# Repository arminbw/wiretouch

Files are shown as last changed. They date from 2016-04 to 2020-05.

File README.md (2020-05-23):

# WireTouch

WireTouch is an open multi-touch tracker based on mutual (projected) capacitance sensing. It was designed and built to foster research in the field of human-computer interaction. Please visit http://www.arminbwagner.com/wiretouch for demos and background information. You may also want to have a look at this paper:

.

The authors are currently not working on further updates. Feel free to fork the project and extend it as you see fit.

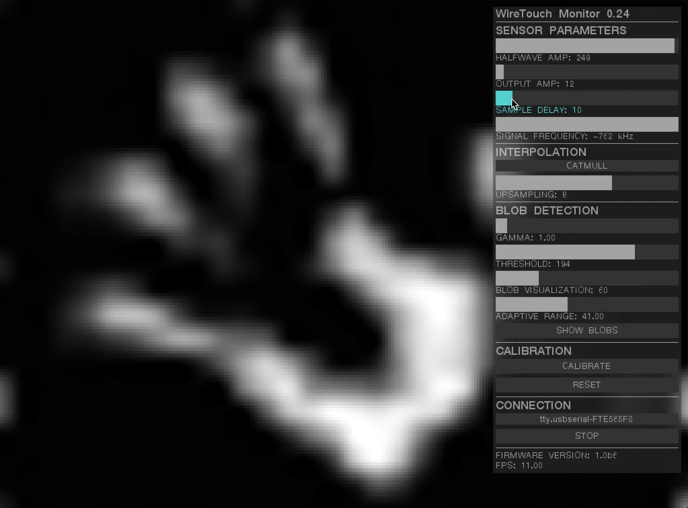
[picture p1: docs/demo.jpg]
WireTouch tracking software showing the interpolated measurements of a hand tracked human hand


## Building
### WireTouch Firmware
1. The heart of the WireTouch hardware is an ATmega328P microcontroller equipped with an Arduino bootloader. To upload the WireTouch firmware, connect the mainboard with your computer. Use an USB to serial UART FTDI 5V cable.

2. Open **hardware/v1.3/firmware/firmware.ino** in the [Arduino IDE](http://arduino.cc/en/Main/Software). Select **Tools>Board>Arduino UNO** and the correct port. **Upload the Arduino sketch.**

Please note: The patched FTDI driver is not working in the latest version of OS X. Please skip step 3 and just use the default (and unfortunately slower) standard Apple FTDI driver. 

~~3. Install the virtual com port [FTDI driver](http://www.ftdichip.com/Drivers/VCP.htm). You need to patch the FTDIUSBSerialDriver configuration to increase the symbol rate of the computer-mainboard connection (see [FTDI Application Note 120](http://www.ftdichip.com/Support/Documents/AppNotes/AN_120_Aliasing_VCP_Baud_Rates.pdf)). We prepared a little perl script for that. Run it as the superuser: ```sudo perl modify-ftdi-driver-settings.pl``` If you are running El Capitan (or a later Mac OS version) you will also have to deactivate the new system integrity protection (SIP) to make this work \(see [issue #1](https://github.com/arminbw/wiretouch/issues/1)\).~~

### WireTouch Monitor
1. Download [openFrameworks 0.8.4](https://github.com/openframeworks/openFrameworks).
2. Download the following openFrameworks addons and put them into your openFrameworks ```addons``` directory:.

  * [ofxCv](https://github.com/kylemcdonald/ofxCv)
  * [ofxUI](https://github.com/rezaali/ofxUI)
  * [ofxBlobsManager](https://github.com/peteruithoven/ofxBlobsManager)

3. Copy the wiretouch_monitor directory of this repository into your openFrameworks ```apps/myApps/``` directory.
4. We are currently using Xcode 7.3 on OSX 10.11.4 for development. Open the Xcode project. **Build it**.

Next to the openFrameworks addons we are also using several other 3rd-party libraries. You do not have to download them manually as they already reside inside the src/3rd-party directory (This list is just for future reference and to give credit).
* [cjson](https://github.com/DaveGamble/cJSON)
* [oscpack](http://code.google.com/p/oscpack)
* [TUIO C++ library](https://github.com/mkalten/TUIO11_CPP)

## License
WireTouch is free software: you can redistribute it and/or modify it under the terms of the GNU General Public License as published by the Free Software Foundation, either version 3 of the License, or (at your option) any later version.

A few of the included 3rd-party libraries are licensed under the GPL-compatible MIT license.

WireTouch is distributed in the hope that it will be useful, but WITHOUT ANY WARRANTY; without even the implied warranty of merchantability or fitness for a particular purpose. See the [GNU General Public License](http://www.gnu.org/licenses) for more details.

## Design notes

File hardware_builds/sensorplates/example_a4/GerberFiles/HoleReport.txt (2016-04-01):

Tool   Size   Count  Plated

 T1    0.0360    54     Yes

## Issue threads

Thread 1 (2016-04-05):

custom baud not supported by OSX El Capitan

arminbw, 2016-04-05:
The modified FTDI driver won't work in OSX 10.11 out of the box. The reason: every kernel extensions has to be signed now by a developer. And before, the developer has to request a [specific certificate from Apple](https://developer.apple.com/library/mac/documentation/Security/Conceptual/System_Integrity_Protection_Guide/KernelExtensions/KernelExtensions.html).

```sudo kextutil -l /System/Library/Extensions/FTDIUSBSerialDriver.kext```

will return

```Code Signing Failure: not code signed```

arminbw, 2016-04-06:
The current solution to this problem is to [deactivate the system integrity protection](https://developer.apple.com/library/mac/documentation/Security/Conceptual/System_Integrity_Protection_Guide/ConfiguringSystemIntegrityProtection/ConfiguringSystemInt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):
* Boot to Recovery OS by restarting your machine and holding down the Command and R keys at startup.
* Launch Terminal from the Utilities menu.
* Enter the following command:
```csrutil enable```

Closed 2016-04-13.

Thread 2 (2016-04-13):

Mesuare capacitance

Mewiss, 2016-04-13:
Hi! I'm making a simple touch screen and I'm having problems with connections to measure capacitance. Do you have any full schematic or diagram about this part.

Thanks!

arminbw, 2016-04-13:
Hi! Which connections exactly are troubling you?

Mewiss, 2016-04-14:
I dont' understand how you connect electrodes with sensor board

arminbw, 2016-04-15:
We connected our sensor panel directly to the sensor board using 2.54mm pin headers. Of course you can use whatever connection you want. Just keep in mind that long cables might diminish the signal quality.

Closed 2016-04-22.

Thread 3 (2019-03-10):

Can't get image from the WireTouch Monitor

hongyu4671, 2019-03-10:
Hi guys,

I have followed the Wiretouch project description step by step. When the circuit (v1_30) and the sensor plate are finished, I have changed all parameters, unfortunately still can not get any image. When I change the “HALFWAVE AMP” in WireTouch Monitor 0.24, nothing changed (see in attachment "Screen Recording").  The parameters look like worked well.

> OSX Version: 10.14.3
> Xcode Version: 9.2
> (I used OPA2350EA/250 for main-board, sensor-board and signal-board).

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

Does anyone have the same problem?
#Question

Closed 2019-03-10.

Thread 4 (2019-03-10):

Can't get image from the Wiretouch Monitor

hongyu4671, 2019-03-10:
Hi guys,

I have followed the Wiretouch project description step by step. When the circuit (v1_30) and the sensor plate are finished, I have changed all parameters, unfortunately still can not get any image. When I change the “HALFWAVE AMP” in WireTouch Monitor 0.24, nothing changed (see in attachment "Screen Recording").  The parameters look like worked well.

> OSX Version: 10.14.3
> Xcode Version: 9.2
> (I used OPA2350EA/250 for main-board, sensor-board and signal-board).

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

Does anyone have the same problem?
#Question

arminbw, 2019-03-14:
Hi Hong,

Your build looks great! Let’s hope we can get it to going soon.

I’ve had a look at the video you sent me and the images look a bit too uniform to me. Also, the halfwave amp doesn't seem to do much at all. But before we go into that, please try the following:
- Set *sample delay* to 1.
- Set *output amp* to 1.
- Set the *frequency* to something high, like 640 kHz or higher.
- Now turn up the *halfwave amp* until the first white dots start to appear on the black screen.
- Now hold your hand above the sensor matrix. Put something in-between the wires and your hand. Don’t touch the wires themselves. Now slowly turn up the output amp until you see your hand.

If you still get nothing, you will need an oscilloscope to narrow down the problem.
- First of all alter the firmware, so it only measures a single crosspoint. I am doing that in my video at <a href="https://www.youtube.com/watch?v=rSD9vQ2_fLQ&feature=youtu.be&t=417">7:18</a>. Set `sample = measure_one(4, 4);` Now you are measuring a single point in the upper left corner of the matrix.
* Now search for the signal where the signal board connects with the sensor matrix. One of the "columns" of the matrix should show a clean 5V wave. If not, something is wrong on the signal board – or the main board.
* If you found your wave, let’s check the sensor board. Be careful, though. You don’t want to short circuit anything! First open the sensor-board_v1_3.brd file to get an overview. Then have a look at PIN 5 of U13 (the first multiplexer). Does the oscilloscope show a wave? Does its amplitude decrease when you put your fist over the upper left corner of your matrix?

hongyu4671, 2019-03-20:
Dear Armin,

thanks for your reply.

After I set the sample delay to 1, output amp to 1 and frequency to 640kHz, I try to increase the halfwave amp to get some dots. Only when I set gamma to 16.00, then I can get some grey dots. But I can't get the hand shape by turning the output amp(video in attachment).

As you said, I set sample = measure_one(4, 4), at first, I can get a 5v wave from pin7 in signal board (picture in attachment). I felt there have some open circuit in the signal board (I use a socket to connect the ICs), after I presse the Multiplexer in signal board then I can't get any thing.

I will make new main and signal board. If I get something new, I will update this issue.

Thanks a lot for your advices!

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

arminbw, 2019-03-30:
I am not sure, if I understood you correctly. When you *remove* the multiplexer from your signal board, you can measure a 5V wave at P7 (compare attachment)?

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

hongyu4671, 2019-04-07:
Dear Arminbw,

I have made new main, signal and sensor board (without socket). As you suggested, I have measured some pins.

- with code: measure_one(4, 4)
I got a 5v from pin5 of Signal_board
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

- with code: measure_one(4, 4)
I got a wave from PIN5 of U13 of Sensor_board. After I **_press_** the matrix, the Vmin and Vbas decreased, Vpp increased. (Without press, just touch the matrix, the signal can not decrease that much)
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

- with code: measure_one(m, l)
the pins, which connect with the matrix, seemed like work well. (The signals have the shift)
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

- with code: measure_one(m, l)
when I pressed the matrix, I can only see some black lines. I can not tune the parameters to get the hand shape.
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

Thanks a lot for your advices!

arminbw, 2019-04-13:
OK, let me try to sum this up: You rebuild all boards and you get different results now. So there was something wrong with the old ones. I suspect there was a short on the signal board, but we don't know for sure.

The measurement you made with measure_one(4,4) on the new setup tells us the following:

* The signal board is sending a nice 5V square wave to the sensor matrix.

* The sensor board is receiving the coupled wave.

* The observable changes on PIN5 on UI13 are very small.

Please note: the matrix shouldn't be pressed. We are not measuring contact or pressure, but proximity by altering the electrical field.

I covered my sensor matrix with a 1.5mm thick glass plate, which I took out of a picture frame. Please try that or something similar and see if you can still see small changes on PIN5 of U13 on the sensor board when you put your fist on the upper left corner of the matrix (measure_one(4,4)). The difference can be very subtle, but it should be still noticeable on the oscilloscope. The image I attached shows what I get at 132kHz and at ca. 750kHz.

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

If your measurements look different, you might want to try other surface materials. Also try using different wires for your sensor matrix. Don't rebuild the whole matrix. Just build a single cross point for testing purposes.

If you get something similar, you should be able to measure the same signals where the sensor board connects with the mother board - on P4. Now follow the traces further. Measure PIN3 of OPAMP-3 on the motherboard while pulling up the "halfwave amp" in the GUI. How does it look like? Can you still spot a difference when you put your fist on the glass?

arminbw, 2019-04-13:
As a side note: I think it’s a typo, but if you want to measure the whole matrix, change the firmware code back to `measure_one(k, l)` not `measure_one(m, l)`.

hongyu4671, 2019-04-22:
I have changed the cover material to 1.5mm glass. As you suggested, I use two Dupont Line to make the cross. Now I can get some big change of the signal.

- Code: measure_one(4,4)    I can get nearly 1V change from the Pin5 of U13
Before put fist (Pin5 of U13)
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
After put fist (Pin5 of U13)
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

- Code: measure_one(4,4)    when I change "halfwave amp" signal from Pin3 of OPAMP-3 (mother board) can get the change as in the following pics
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

- Code: measure_one(4,4)    When I put my fist on the glass, I can see some change in the viewer of GUI. When I put my fist on, It seems like more dots came out
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

The PCB boards seems like works good, is it time to rebuild the matrix on glass?

Btw, its a typo for the (m, l)

arminbw, 2019-04-25:
Image 1 and 2 look pretty good.

Regarding image 3 and 4, where you measure Pin3 of OPAMP-3: Did you reduce the frequency (269kHz?) here to get better measurements? If not, something might be wrong here. And can you still see a difference in the wave when you lift and lower your fist?

Please don’t rebuild the matrix until we get a clear visual difference on the screen. I am not speaking of some dots. The whole screen should turn from black to white while you lower your fist on the crosspoint.

arminbw, 2019-05-26:
Hi Hong, did you make any progress? Can I support you in any way?

hongyu4671, 2019-05-28:
Dear Armin,

these days I have to solve other project problem, next month I will check the circuit.

And one more question, I want to use the circuit and the software for a thin films structure (bottom and top electrode: 50nm gold, insolation layer: 100nm Al2O3). Is it possible to use the circuit and software for the thin film device?

Best regards,
Yu Hong
在 2019年5月26日 +0200 17:04，Armin <notifications@github.com>，写道：
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

hongyu4671, 2019-06-19:
Hi Arminbw,
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
hongyu4671, 2019-06-19:
And one more thing, I turn off oscilloscope, remove the connection from Pin3 of OPAMP-3, but still connect the ground pin from mainboard with the oscilloscope's ground, the result are good as below.
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

hongyu4671, 2019-06-20:
Hi Arminbw,

If I didn't misunderstand the code, _**measure_one(k, l)**_,  when we change the **_k_**, the signal from signal board should change.

When we use _**measure_one(0, 0)**_, the signal should come from Pin 1 of signal board,
_**measure_one(1, 0)**_, signal should from Pin 2, right?

But when I change the code, the signal doesn't have any change, It comes always from **Pin 7** and **Pin 23**, which should get with code _**measure_one(6, l)**_ and _**measure_one(22,l)**_

All the signals are same like bellow.
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

arminbw, 2019-07-08:
Hi Hong,

a change from 25mV to 18mV seems pretty good to me. The video you posted (where you are using 640kHz) looks good too, but the screen should be black when your hand is raised, not grey.

Try to reduce the halfwave amp a bit while lifting your hand. Turn it lower than 247. The screen should be black. Then try to increase the output amp a little bit (higher than 1). When the screen turns grey, reduce the output amp a bit again, so the screen is black again. It can be a bit tricky to get the best range/sensitivity.

Regarding your other question: Yes, grounding the oscilloscope while making measurement helps. The motherboard has an extra pin to support that. Just be careful to not short anything. And yes, grounding the board and making measurements can alter the images you will see. Grounding your laptop (connecting it with a different power supply etc.) might also change the results. Unfortunately there are lots of variables.

Regarding your last post: **Yes, `measure_one(0,0)` should only send the signal to Pin 1.** If you see the wave at Pin 7 and/or Pin 23, something is wrong. Maybe the software isn't running – or maybe the multiplexer isn't working correctly. You could test this with the oscilloscope.
**The following image shows what mux1 should do when you set `sample = measure_one(1, 0).`**

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

hongyu4671, 2019-07-15:
Hi arminbw,

I have tested the 2 MUX in signal board, the signal looks good. I think last time, I forgot to run the software.

- With code **measure_one(1,1)**, after tuning the parameter I can get the screen from black to grey (when my fist touch the wire), when my other hand hold the ground, it can go to white (when my fist touch the wire).
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
with the circuit below:
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

- With code  **measure_one(1,1)**, when I changed the circuit to 6 signal lines, 8 sensor lines (circuit below), I can not get the same good result as before.
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

- With code **measure_one(k, l)**, (k=6, l=8), noise came up, and it can not be removed.
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

arminbw, 2019-10-17:
Hi Hong, sorry for the long delay. I will try to replicate your setup over the weekend.

arminbw, 2019-11-24:
I am trying to sum up your last post and comment on it point-by-point:

* Your MUX seems to work correctly. That’s good!
* `measure_one(1,1)` gives you promising results. Looking at your photo, I would suggest putting the glass **not in-between** the wires, but **on top of it**. Your hand should not touch the wires directly.
* When you set `signalboardWires = 6` and `sensorboardWires = 8` you get diagonal black lines. The lines you are seeing are not necessarily noise. Your board´s firmware is sending 6x8 crosspoints to your computer, but wiretouch.app is still expecting 32x22 crosspoints. To get a correct visualization you would need to change the values in `wtmApp.h` and then re-compile the software.

An easier way to quickly check if your small 6x8 build is working, is to set your firmware code back to 32x22 crosspoints. The screen should turn all white with a little black rectangle inside.

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

I tried to replicate your setup (see pictures above). I can track some movement in the black area, but there is a lot of noise bleeding in. I would suggest to increase the distance of the wires (e.g. 1cm x 1cm squares) and to try different wire gauges. I’m sorry that I can’t give you better advise at the moment than to basically ”play with all parameters”. Debugging hardware prototypes remotely is …not easy.

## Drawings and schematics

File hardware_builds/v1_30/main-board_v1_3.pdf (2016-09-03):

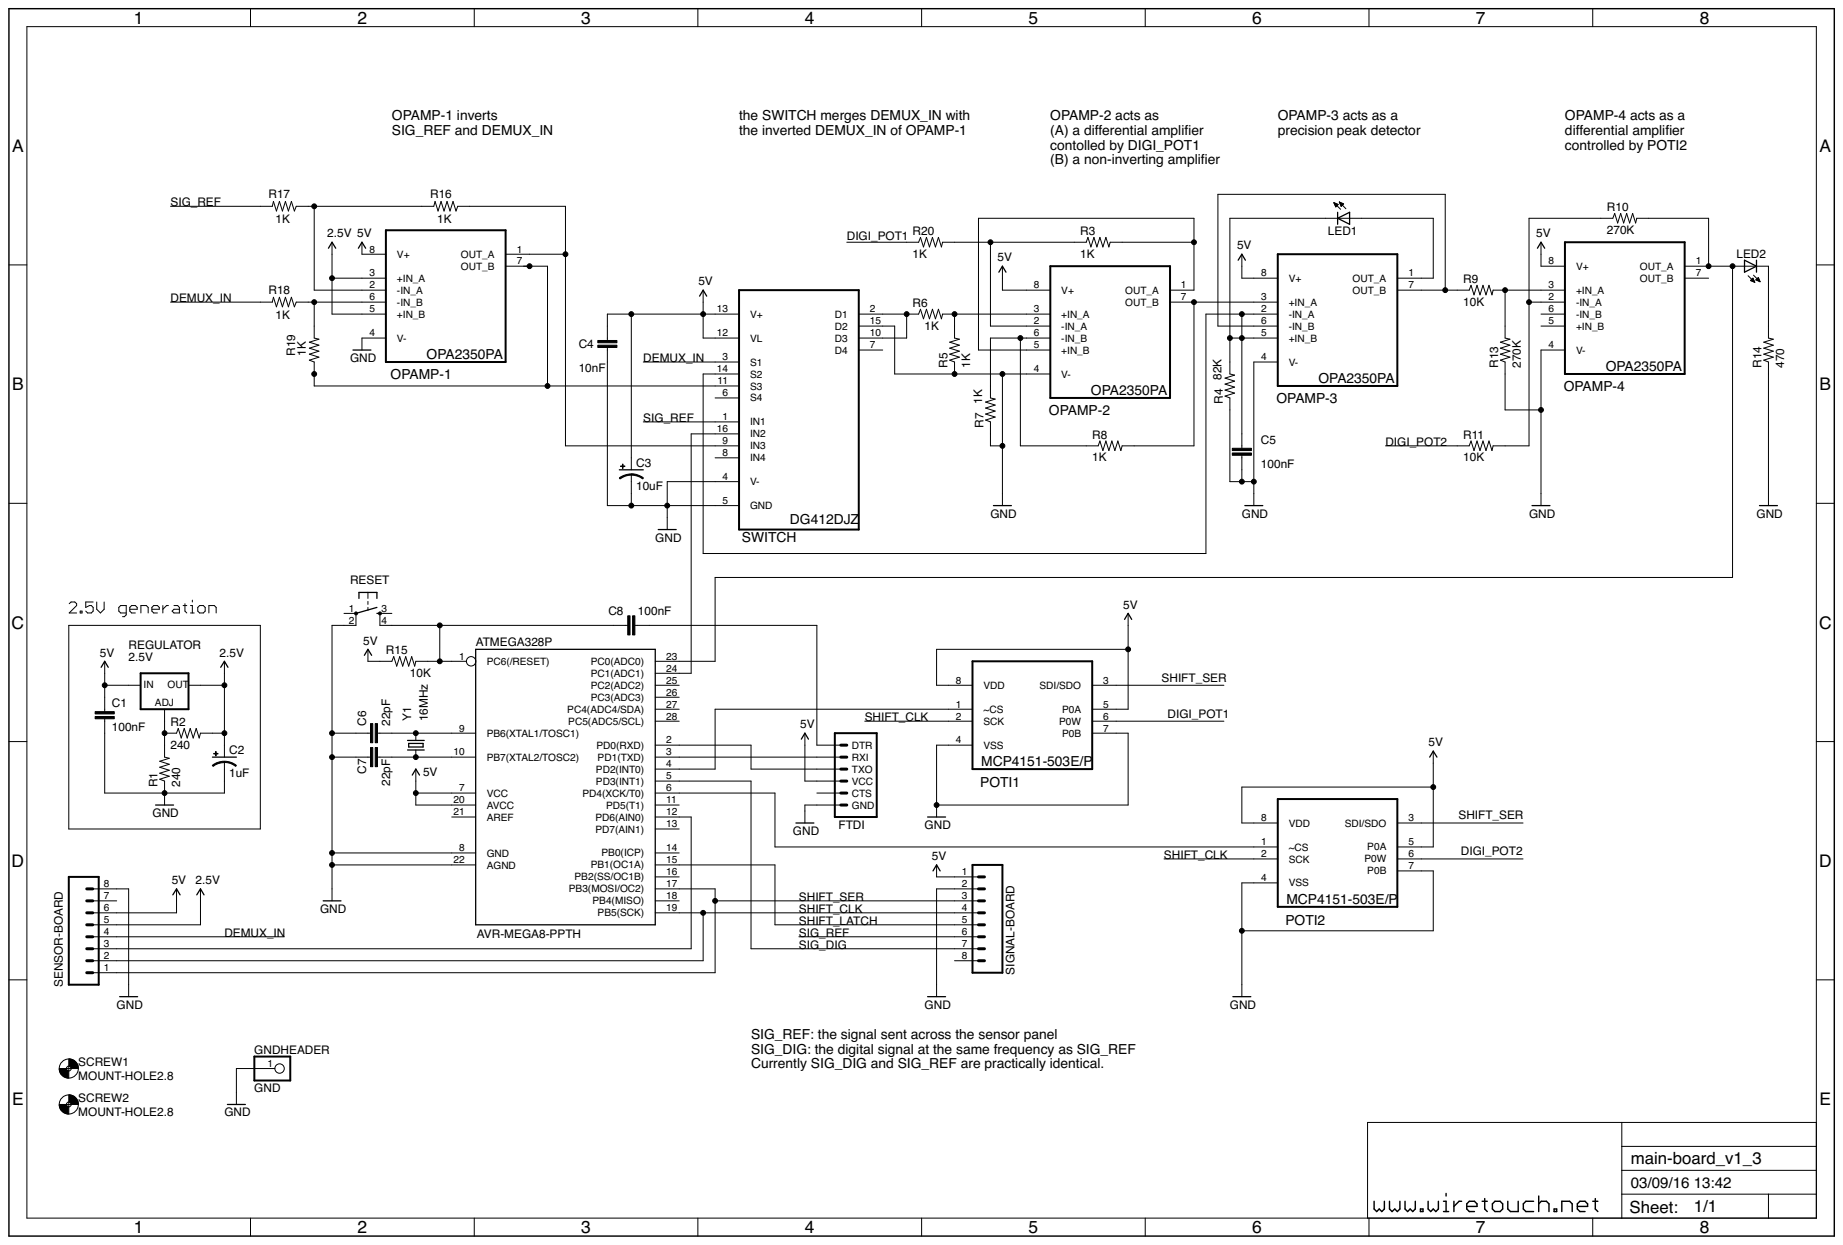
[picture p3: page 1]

(B) a non-inverting amplifier OPAMP-1 inverts SIG_REF and DEMUX_IN

the SWITCH merges DEMUX_IN with
the inverted DEMUX_IN of OPAMP-1

differential amplifier controlled by POTI2 OPAMP-2 acts as
(A) a differential amplifier contolled by DIGI_POT1

SIG_REF: the signal sent across the sensor panel SIG_DIG: the digital signal at the same frequency as SIG_REF Currently SIG_DIG and SIG_REF are practically identical.

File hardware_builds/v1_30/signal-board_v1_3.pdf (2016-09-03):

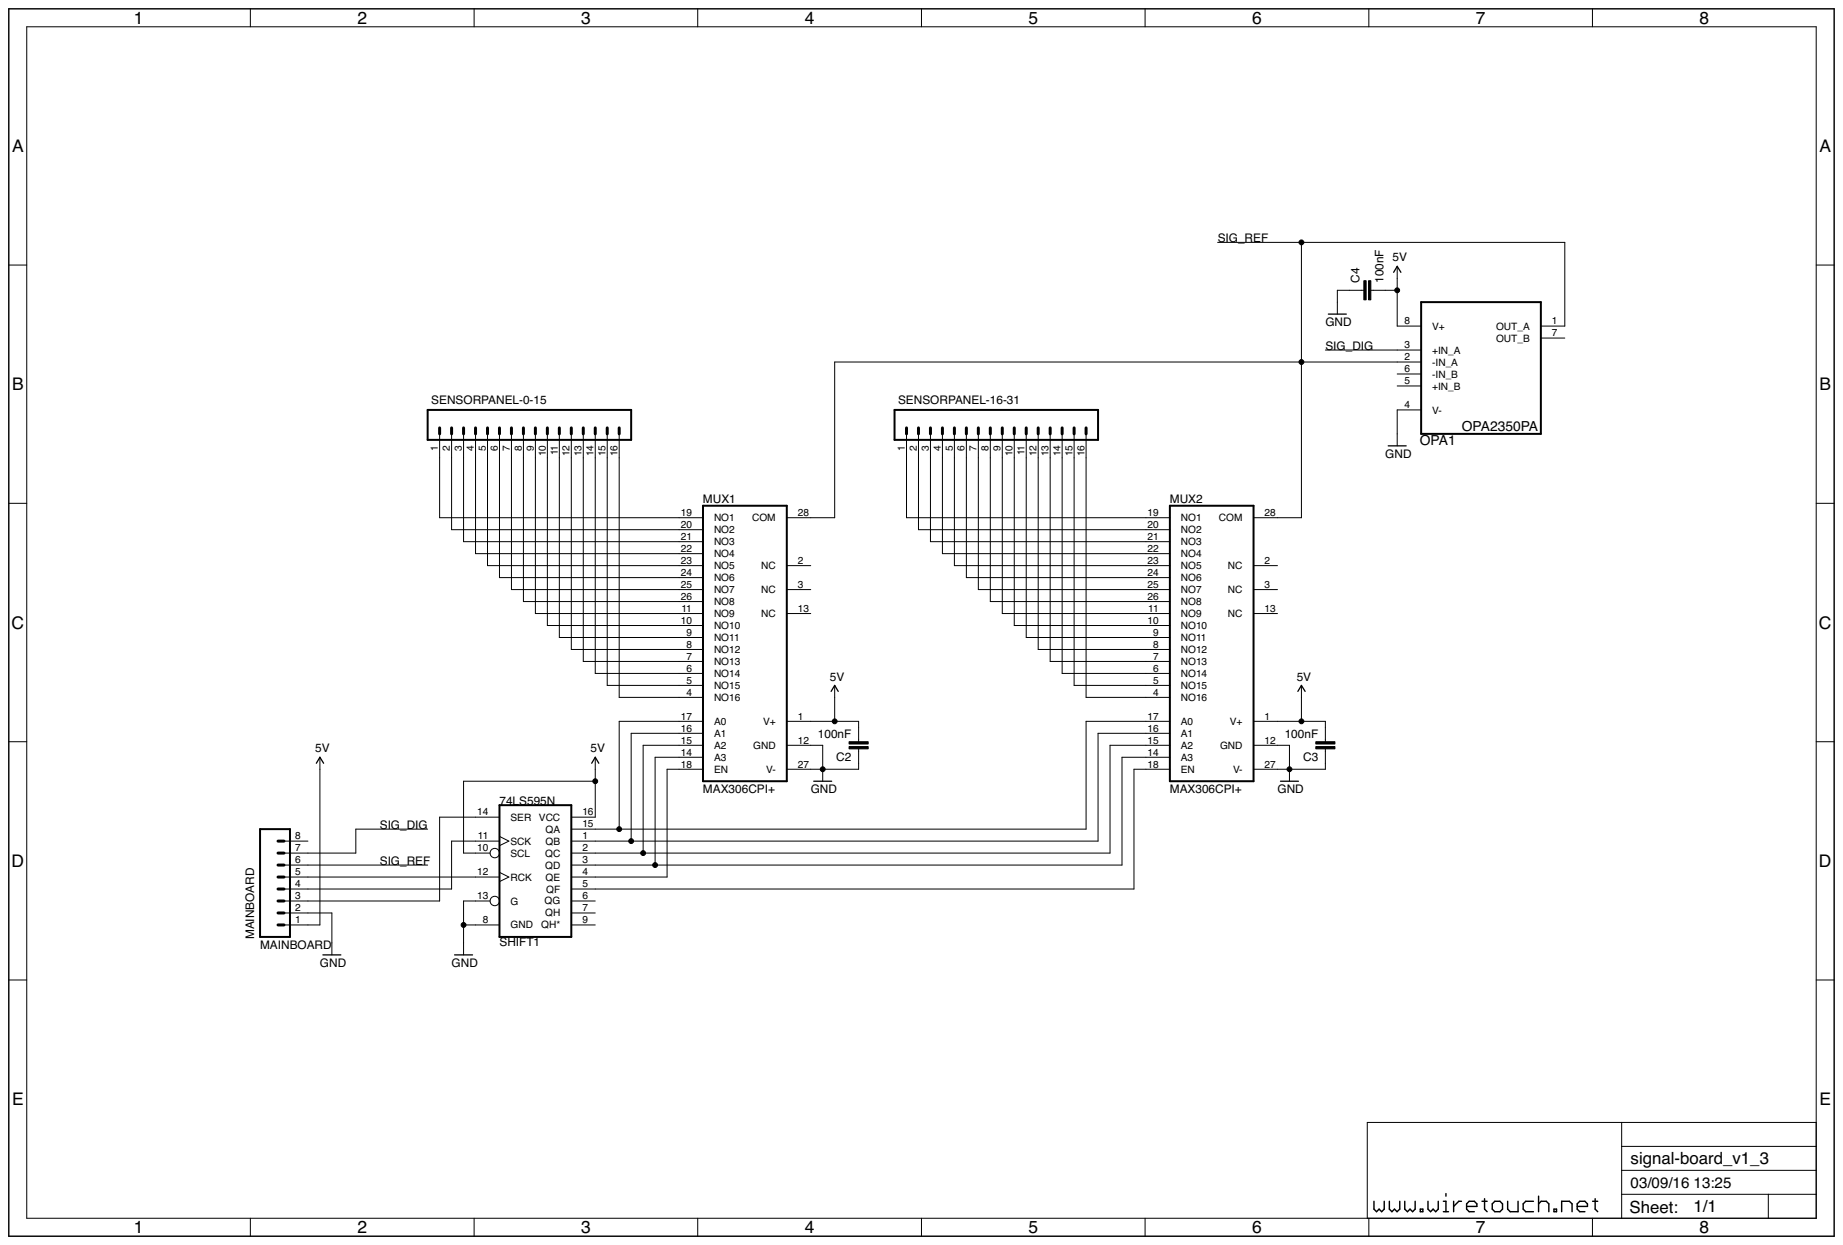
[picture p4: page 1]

4 | | | 13 | | 4 QF
3 | | | | | 5 QG
2 | | 8 | | 6 QH

1 | GND

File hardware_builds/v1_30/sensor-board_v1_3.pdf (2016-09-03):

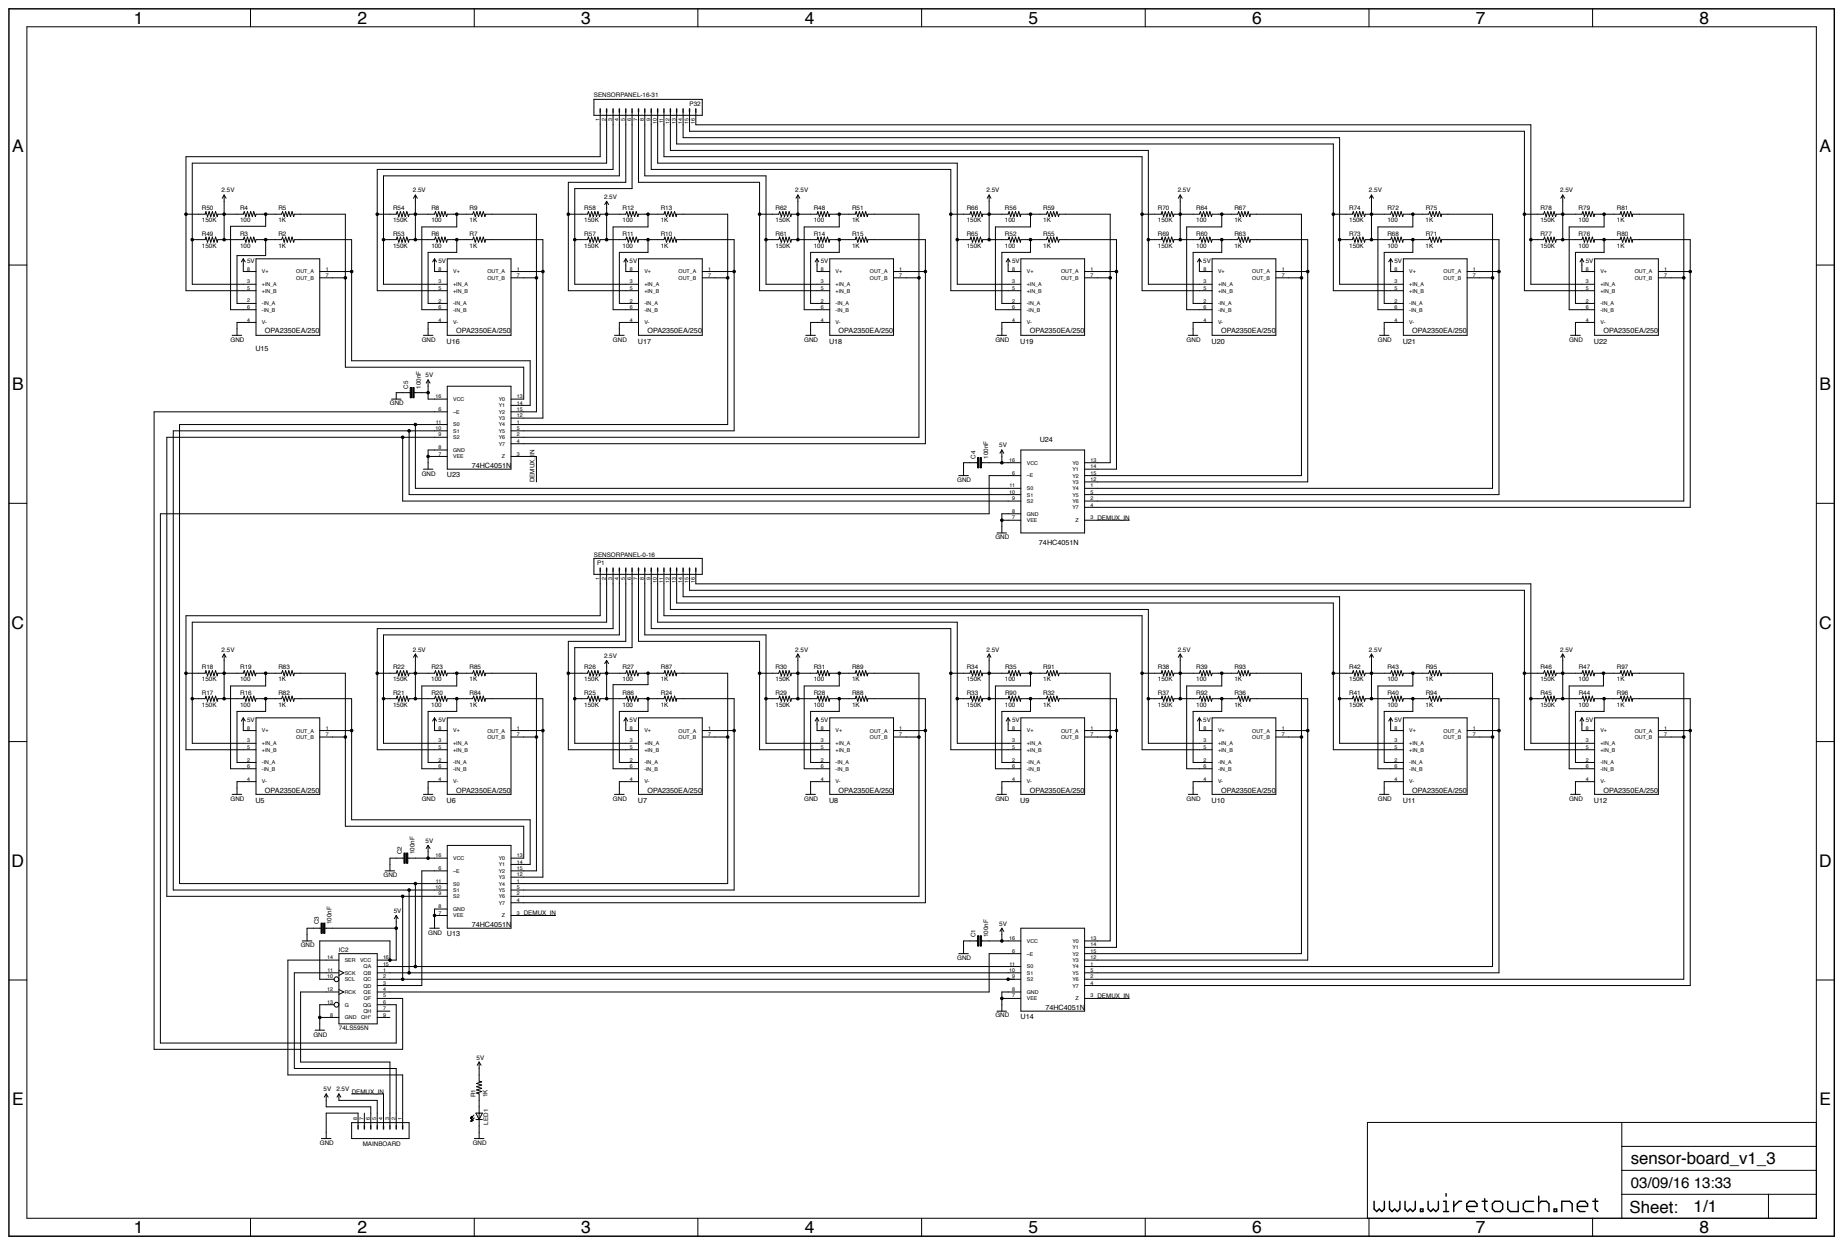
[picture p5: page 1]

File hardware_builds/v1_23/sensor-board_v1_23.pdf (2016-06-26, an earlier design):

A

A

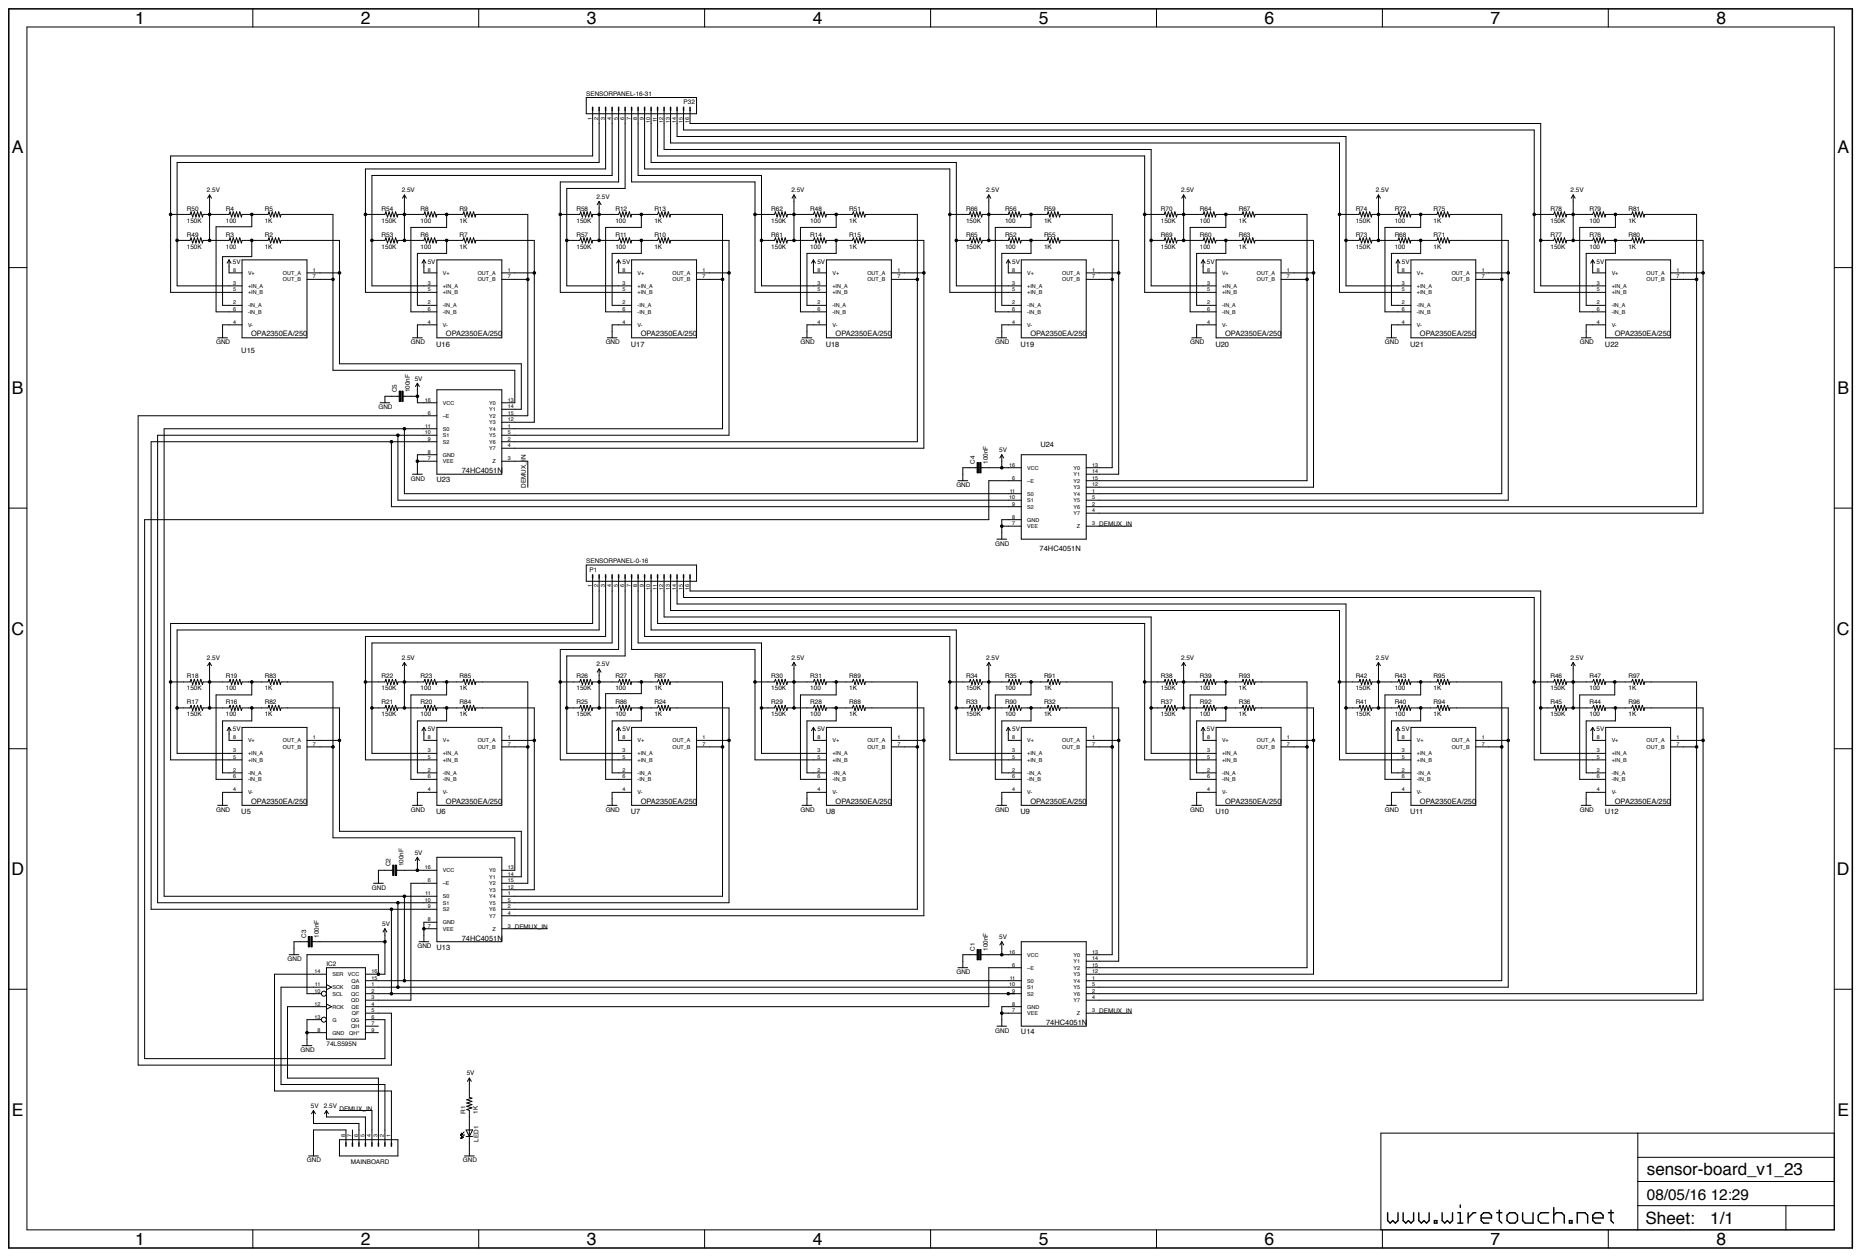
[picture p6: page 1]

S1 10
S2 9
GND 8 VEE 7

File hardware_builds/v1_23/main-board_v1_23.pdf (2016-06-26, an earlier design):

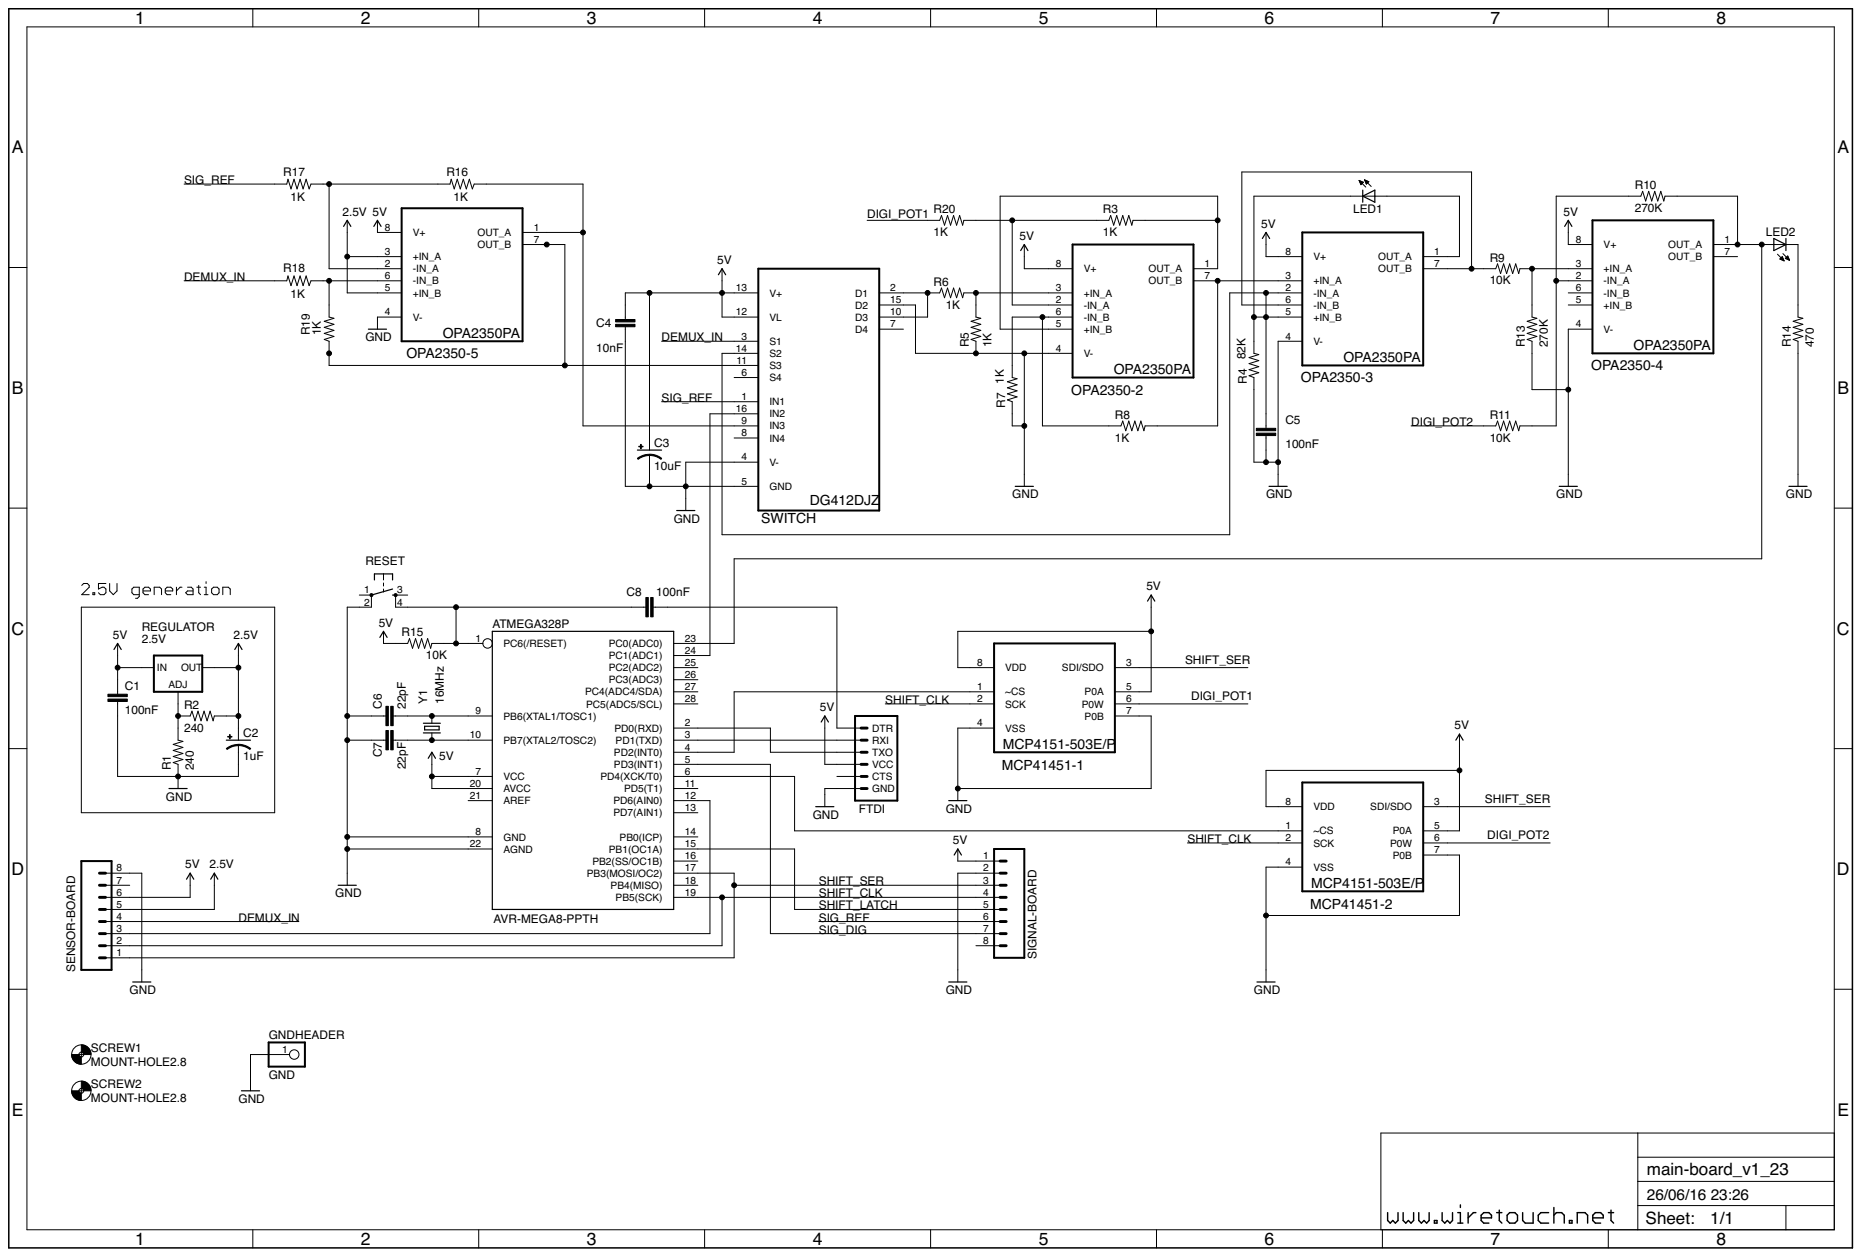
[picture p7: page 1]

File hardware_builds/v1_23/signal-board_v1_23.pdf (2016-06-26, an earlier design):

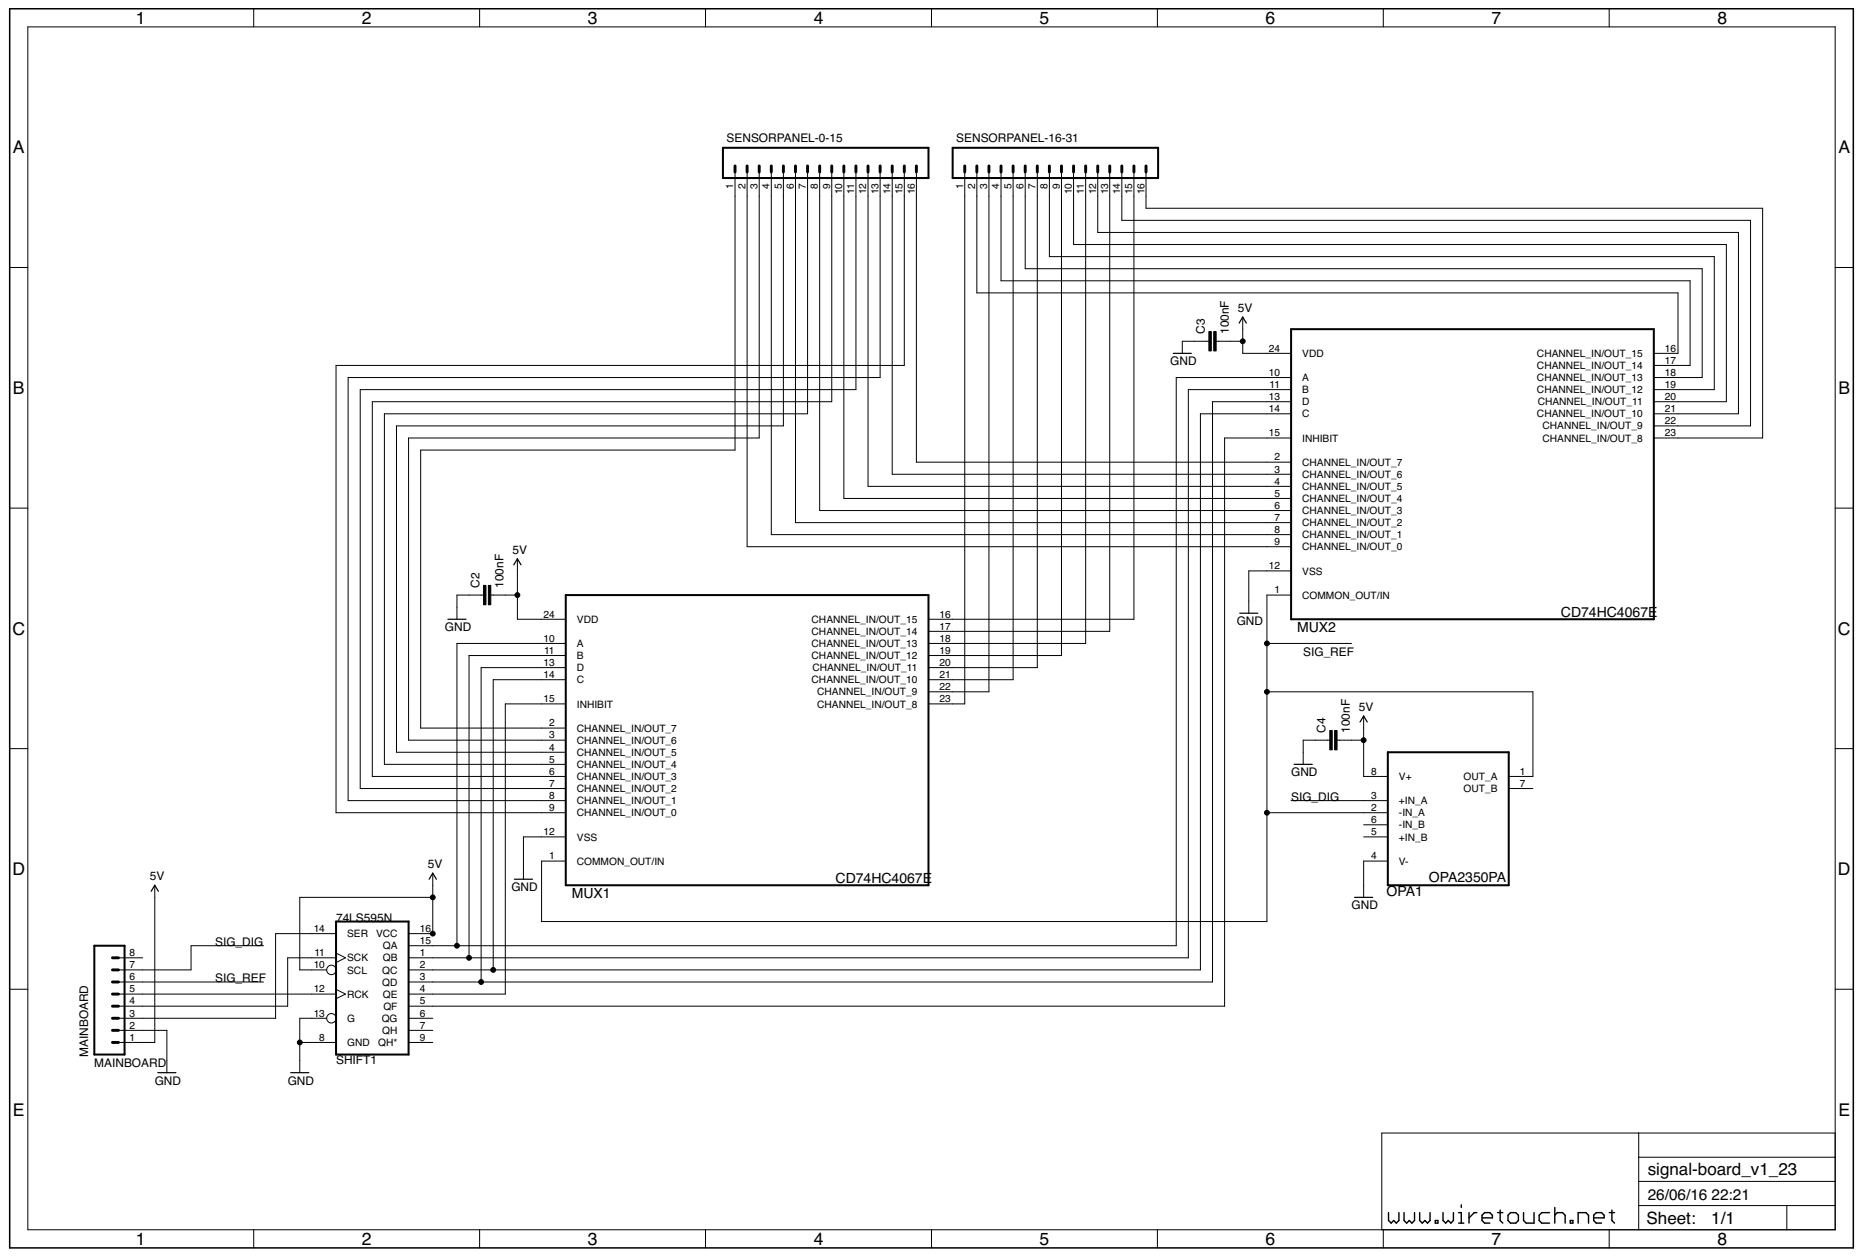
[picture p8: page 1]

17 CHANNEL_IN/OUT_13 18 CHANNEL_IN/OUT_12

19 CHANNEL_IN/OUT_11
20 CHANNEL_IN/OUT_10
21 CHANNEL_IN/OUT_9

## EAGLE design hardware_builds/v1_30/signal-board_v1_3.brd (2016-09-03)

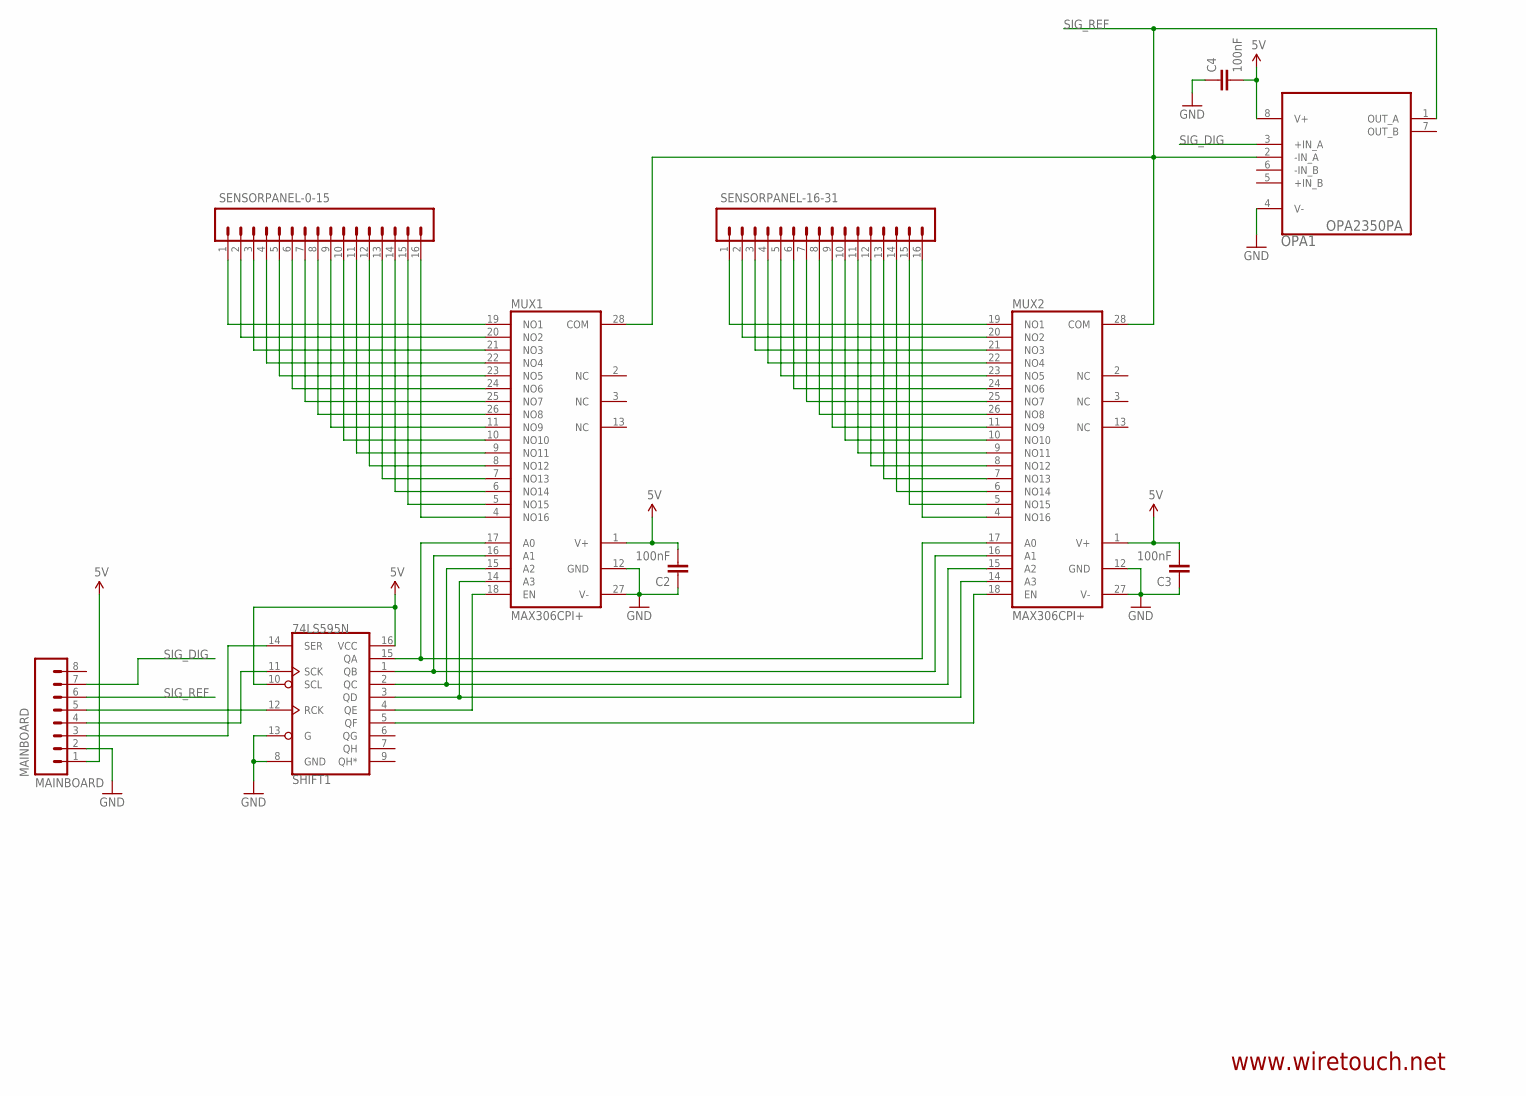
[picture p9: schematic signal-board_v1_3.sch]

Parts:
C2, C3, C4: 100nF; CAP-PTH-SMALL
MAINBOARD: MAINBOARD; 1X08_LONGPADS
MUX1, MUX2: MAX306CPI+; DIL28-6
OPA1: OPA2350PA; DIP254P762X508-8
SENSORPANEL-0-15, SENSORPANEL-16-31: M16LOCK_LONGPADS; 1X16_LOCK_LONGPADS
SHIFT1: 74LS595N; DIL16

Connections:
5V: C2.2, C3.2, C4.2, MAINBOARD.1, MUX1.1 (V+), MUX2.1 (V+), OPA1.8 (V+), SHIFT1.10 (SCL), SHIFT1.16 (VCC)
GND: C2.1, C3.1, C4.1, MAINBOARD.2, MUX1.12 (GND), MUX1.27 (V-), MUX2.12 (GND), MUX2.27 (V-), OPA1.4 (V-), SHIFT1.8 (GND), SHIFT1.13 (G)
unnamed: MUX1.19 (NO1), SENSORPANEL-0-15.1
unnamed: MUX1.21 (NO3), SENSORPANEL-0-15.3
unnamed: MUX1.23 (NO5), SENSORPANEL-0-15.5
unnamed: MUX1.25 (NO7), SENSORPANEL-0-15.7
unnamed: MUX1.11 (NO9), SENSORPANEL-0-15.9
unnamed: MUX1.9 (NO11), SENSORPANEL-0-15.11
unnamed: MUX1.7 (NO13), SENSORPANEL-0-15.13
unnamed: MUX1.5 (NO15), SENSORPANEL-0-15.15
unnamed: MUX2.19 (NO1), SENSORPANEL-16-31.1
unnamed: MUX2.21 (NO3), SENSORPANEL-16-31.3
unnamed: MUX2.23 (NO5), SENSORPANEL-16-31.5
unnamed: MUX2.25 (NO7), SENSORPANEL-16-31.7
unnamed: MUX2.11 (NO9), SENSORPANEL-16-31.9
unnamed: MUX2.9 (NO11), SENSORPANEL-16-31.11
unnamed: MUX2.7 (NO13), SENSORPANEL-16-31.13
unnamed: MUX2.5 (NO15), SENSORPANEL-16-31.15
unnamed: MUX1.20 (NO2), SENSORPANEL-0-15.2
unnamed: MUX1.22 (NO4), SENSORPANEL-0-15.4
unnamed: MUX1.24 (NO6), SENSORPANEL-0-15.6
unnamed: MUX1.26 (NO8), SENSORPANEL-0-15.8
unnamed: MUX1.10 (NO10), SENSORPANEL-0-15.10
unnamed: MUX1.8 (NO12), SENSORPANEL-0-15.12
unnamed: MUX1.6 (NO14), SENSORPANEL-0-15.14
unnamed: MUX1.4 (NO16), SENSORPANEL-0-15.16
unnamed: MUX2.20 (NO2), SENSORPANEL-16-31.2
unnamed: MUX1.16 (A1), MUX2.16 (A1), SHIFT1.1 (QB)
unnamed: MUX1.17 (A0), MUX2.17 (A0), SHIFT1.15 (QA)
unnamed: MUX1.15 (A2), MUX2.15 (A2), SHIFT1.2 (QC)
unnamed: MUX2.22 (NO4), SENSORPANEL-16-31.4
unnamed: MAINBOARD.3, SHIFT1.14 (SER)
unnamed: MUX1.18 (EN), SHIFT1.4 (QE)
unnamed: MUX2.18 (EN), SHIFT1.5 (QF)
unnamed: MAINBOARD.4, SHIFT1.11 (SCK)
unnamed: MUX1.14 (A3), MUX2.14 (A3), SHIFT1.3 (QD)
unnamed: MAINBOARD.5, SHIFT1.12 (RCK)
unnamed: MUX2.24 (NO6), SENSORPANEL-16-31.6
unnamed: MUX2.26 (NO8), SENSORPANEL-16-31.8
unnamed: MUX2.10 (NO10), SENSORPANEL-16-31.10
unnamed: MUX2.8 (NO12), SENSORPANEL-16-31.12
unnamed: MUX2.6 (NO14), SENSORPANEL-16-31.14
unnamed: MUX2.4 (NO16), SENSORPANEL-16-31.16
SIG_DIG: MAINBOARD.7, OPA1.3 (+IN_A)
SIG_REF: MAINBOARD.6, MUX1.28 (COM), MUX2.28 (COM), OPA1.1 (OUT_A), OPA1.2 (-IN_A)

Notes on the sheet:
www.wiretouch.net

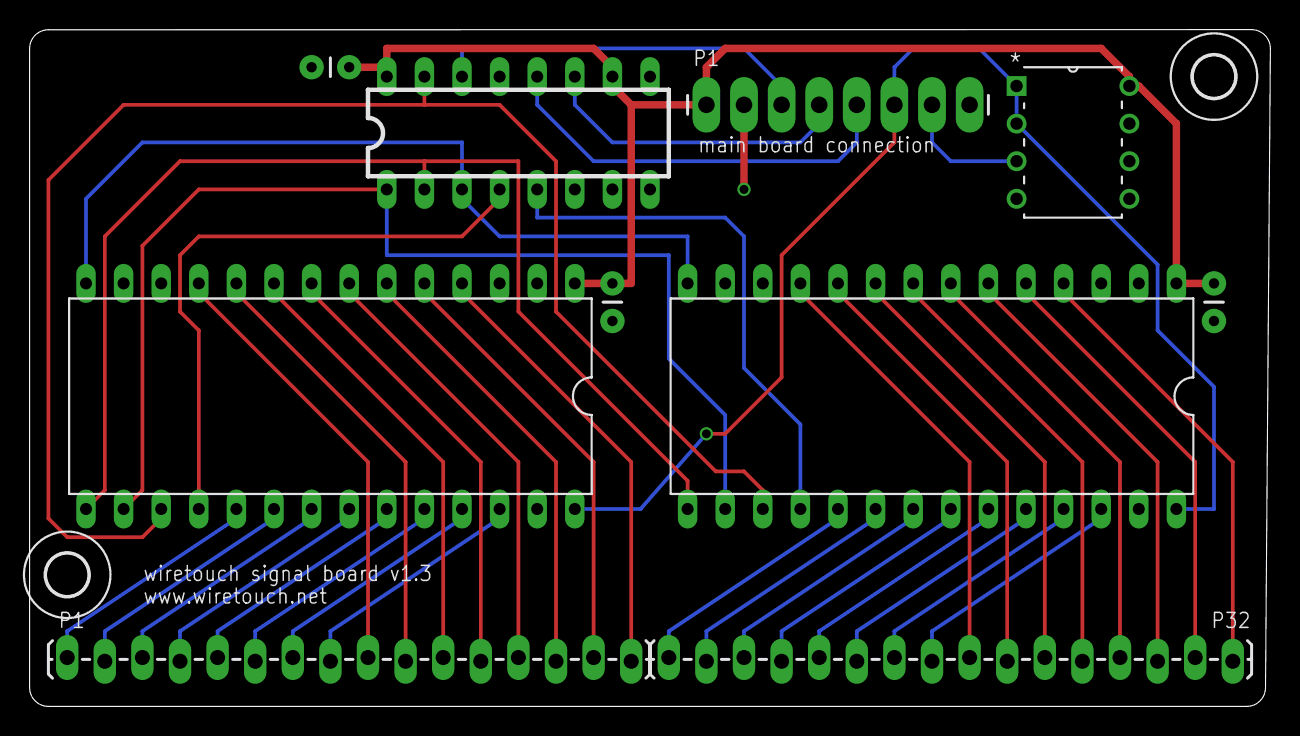
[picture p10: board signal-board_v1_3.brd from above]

Board: 2 copper layers, 83.8 x 45.7 mm, 12 parts (0 on the bottom side), 45 nets.

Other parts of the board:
U$6, U$7: 2,8

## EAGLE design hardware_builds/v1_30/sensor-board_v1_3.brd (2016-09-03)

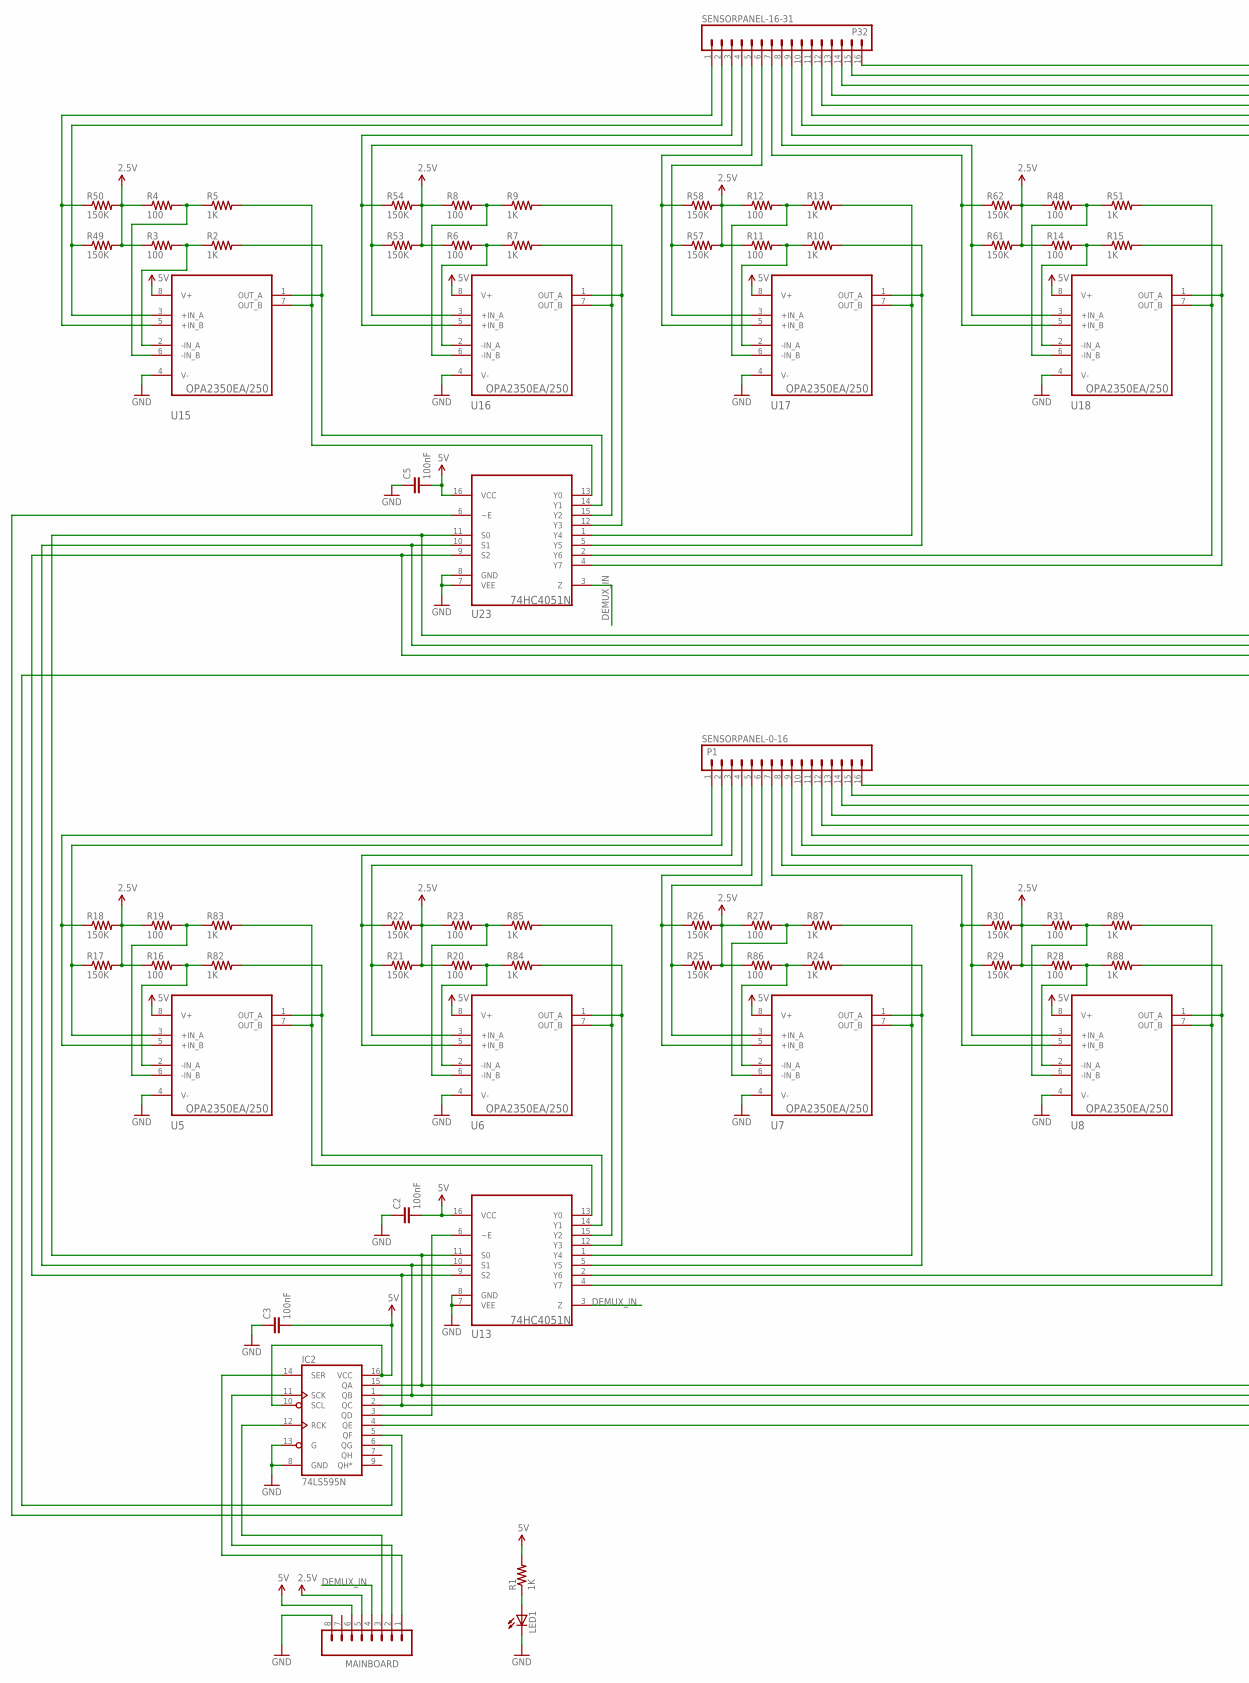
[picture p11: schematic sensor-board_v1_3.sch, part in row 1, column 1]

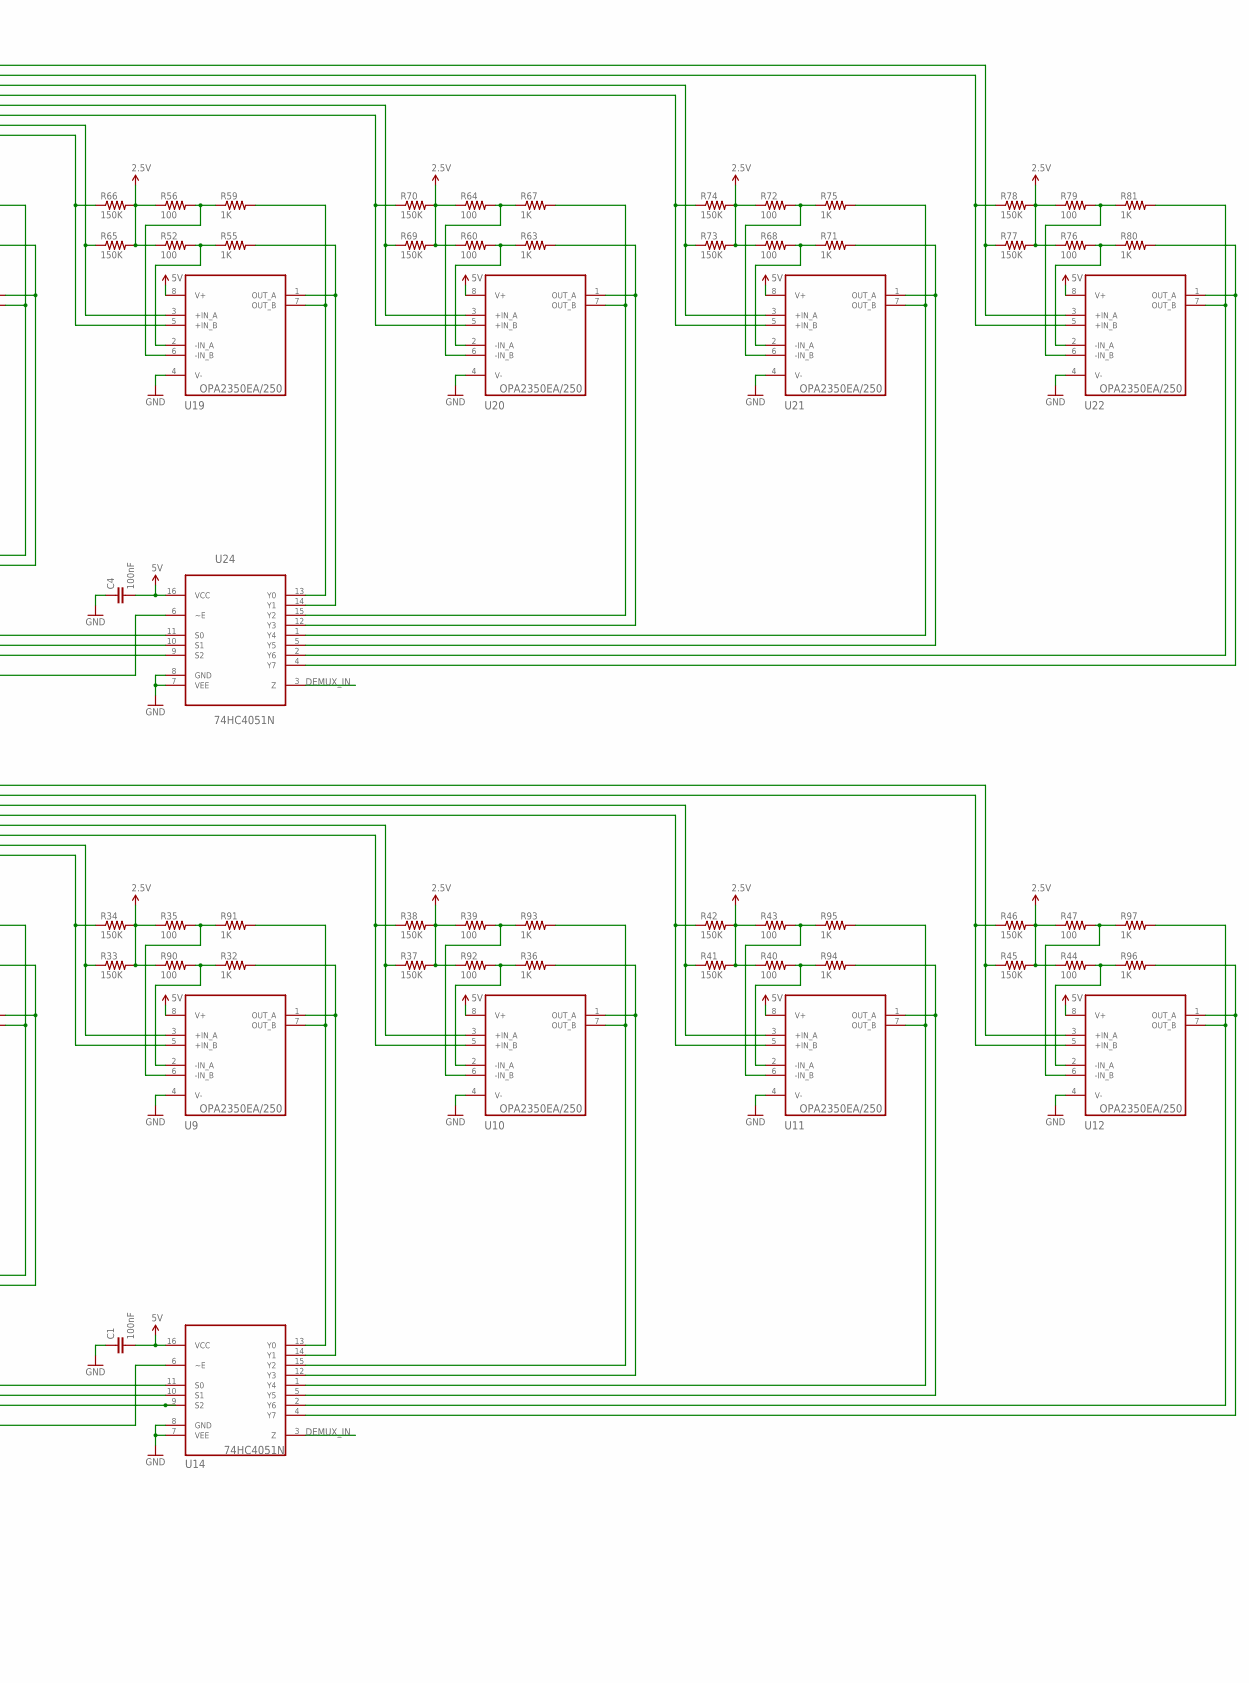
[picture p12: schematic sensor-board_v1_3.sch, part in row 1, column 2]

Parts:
C1, C2, C3, C4, C5: 100nF; CAP-PTH-SMALL
IC2: 74LS595N; DIL16
LED1: LED0603; LED-0603
MAINBOARD: M08LONGPADS; 1X08_LONGPADS
R1, R2, R5, R7, R9, R10, R13, R15, R24, R32, R36, R51, R55, R59, R63, R67, R71, R75, R80, R81, R82, R83, R84, R85, R87, R88, R89, R91, R93, R94, R95, R96, R97: 1K; 0805
R3, R4, R6, R8, R11, R12, R14, R16, R19, R20, R23, R27, R28, R31, R35, R39, R40, R43, R44, R47, R48, R52, R56, R60, R64, R68, R72, R76, R79, R86, R90, R92: 100; 0805
R17, R18, R21, R22, R25, R26, R29, R30, R33, R34, R37, R38, R41, R42, R45, R46, R49, R50, R53, R54, R57, R58, R61, R62, R65, R66, R69, R70, R73, R74, R77, R78: 150K; 0805
SENSORPANEL-0-16: P1; 1X16_LOCK
SENSORPANEL-16-31: P32; 1X16_LOCK
U5, U6, U7, U8, U9, U10, U11, U12, U15, U16, U17, U18, U19, U20, U21, U22: OPA2350EA/250; SOP65P490X110-8N
U13, U14, U23, U24: 74HC4051N; DIP254P762X420-16

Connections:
2.8V: MAINBOARD.5, R3.1, R4.1, R6.1, R8.1, R11.1, R12.1, R14.1, R16.1, R17.2, R18.2, R19.1, R20.1, R21.2, R22.2, R23.1, R25.2, R26.2, R27.1, R28.1, R29.2, R30.2, R31.1, R33.2, R34.2, R35.1, R37.2, R38.2, R39.1, R40.1, R41.2, R42.2, R43.1, R44.1, R45.2, R46.2, R47.1, R48.1, R49.2, R50.2, R52.1, R53.2, R54.2, R56.1, R57.2, R58.2, R60.1, R61.2, R62.2, R64.1, R65.2, R66.2, R68.1, R69.2, R70.2, R72.1, R73.2, R74.2, R76.1, R77.2, R78.2, R79.1, R86.1, R90.1, R92.1
5V: C1.2, C2.2, C3.2, C4.2, C5.2, IC2.10 (SCL), IC2.16 (VCC), MAINBOARD.6, R1.2, U5.8 (V+), U6.8 (V+), U7.8 (V+), U8.8 (V+), U9.8 (V+), U10.8 (V+), U11.8 (V+), U12.8 (V+), U13.16 (VCC), U14.16 (VCC), U15.8 (V+), U16.8 (V+), U17.8 (V+), U18.8 (V+), U19.8 (V+), U20.8 (V+), U21.8 (V+), U22.8 (V+), U23.16 (VCC), U24.16 (VCC)
DEMUX_IN: MAINBOARD.4, U13.3 (Z), U14.3 (Z), U23.3 (Z), U24.3 (Z)
GND: C1.1, C2.1, C3.1, C4.1, C5.1, IC2.8 (GND), IC2.13 (G), LED1.C, MAINBOARD.8, U5.4 (V-), U6.4 (V-), U7.4 (V-), U8.4 (V-), U9.4 (V-), U10.4 (V-), U11.4 (V-), U12.4 (V-), U13.7 (VEE), U13.8 (GND), U14.7 (VEE), U14.8 (GND), U15.4 (V-), U16.4 (V-), U17.4 (V-), U18.4 (V-), U19.4 (V-), U20.4 (V-), U21.4 (V-), U22.4 (V-), U23.7 (VEE), U23.8 (GND), U24.7 (VEE), U24.8 (GND)
unnamed: LED1.A, R1.1
unnamed: R2.1, R3.2, U15.2 (-IN_A)
unnamed: R4.2, R5.1, U15.6 (-IN_B)
unnamed: R6.2, R7.1, U16.2 (-IN_A)
unnamed: R8.2, R9.1, U16.6 (-IN_B)
unnamed: R10.1, R11.2, U17.2 (-IN_A)
unnamed: R12.2, R13.1, U17.6 (-IN_B)
unnamed: R14.2, R15.1, U18.2 (-IN_A)
unnamed: R48.2, R51.1, U18.6 (-IN_B)
unnamed: R52.2, R55.1, U19.2 (-IN_A)
unnamed: R56.2, R59.1, U19.6 (-IN_B)
unnamed: R60.2, R63.1, U20.2 (-IN_A)
unnamed: R64.2, R67.1, U20.6 (-IN_B)
unnamed: R68.2, R71.1, U21.2 (-IN_A)
unnamed: R72.2, R75.1, U21.6 (-IN_B)
unnamed: R76.2, R80.1, U22.2 (-IN_A)
unnamed: R79.2, R81.1, U22.6 (-IN_B)
unnamed: R16.2, R82.1, U5.2 (-IN_A)
unnamed: R19.2, R83.1, U5.6 (-IN_B)
unnamed: R20.2, R84.1, U6.2 (-IN_A)
unnamed: R23.2, R85.1, U6.6 (-IN_B)
unnamed: R24.1, R86.2, U7.2 (-IN_A)
unnamed: R27.2, R87.1, U7.6 (-IN_B)
unnamed: R82.2, U5.1 (OUT_A), U13.14 (Y1)
unnamed: R83.2, U5.7 (OUT_B), U13.13 (Y0)
unnamed: R84.2, U6.1 (OUT_A), U13.12 (Y3)
unnamed: R28.2, R88.1, U8.2 (-IN_A)
unnamed: R17.1, SENSORPANEL-0-16.2, U5.3 (+IN_A)
unnamed: R18.1, SENSORPANEL-0-16.1, U5.5 (+IN_B)
unnamed: R31.2, R89.1, U8.6 (-IN_B)
unnamed: R85.2, U6.7 (OUT_B), U13.15 (Y2)
unnamed: R32.1, R90.2, U9.2 (-IN_A)
unnamed: R21.1, SENSORPANEL-0-16.4, U6.3 (+IN_A)
unnamed: R22.1, SENSORPANEL-0-16.3, U6.5 (+IN_B)
unnamed: R35.2, R91.1, U9.6 (-IN_B)
unnamed: R24.2, U7.1 (OUT_A), U13.5 (Y5)
unnamed: R87.2, U7.7 (OUT_B), U13.1 (Y4)
unnamed: R36.1, R92.2, U10.2 (-IN_A)
unnamed: R25.1, SENSORPANEL-0-16.6, U7.3 (+IN_A)
unnamed: R26.1, SENSORPANEL-0-16.5, U7.5 (+IN_B)
unnamed: R39.2, R93.1, U10.6 (-IN_B)
unnamed: R88.2, U8.1 (OUT_A), U13.4 (Y7)
unnamed: R89.2, U8.7 (OUT_B), U13.2 (Y6)
unnamed: R40.2, R94.1, U11.2 (-IN_A)
unnamed: R32.2, U9.1 (OUT_A), U14.14 (Y1)
unnamed: R30.1, SENSORPANEL-0-16.7, U8.5 (+IN_B)
unnamed: R44.2, R96.1, U12.2 (-IN_A)
unnamed: R29.1, SENSORPANEL-0-16.8, U8.3 (+IN_A)
unnamed: R91.2, U9.7 (OUT_B), U14.13 (Y0)
unnamed: R47.2, R97.1, U12.6 (-IN_B)
unnamed: R34.1, SENSORPANEL-0-16.9, U9.5 (+IN_B)
unnamed: R33.1, SENSORPANEL-0-16.10, U9.3 (+IN_A)
unnamed: R36.2, U10.1 (OUT_A), U14.12 (Y3)
unnamed: R93.2, U10.7 (OUT_B), U14.15 (Y2)
unnamed: R38.1, SENSORPANEL-0-16.11, U10.5 (+IN_B)
unnamed: R37.1, SENSORPANEL-0-16.12, U10.3 (+IN_A)
unnamed: R94.2, U11.1 (OUT_A), U14.5 (Y5)
unnamed: R95.2, U11.7 (OUT_B), U14.1 (Y4)
unnamed: R42.1, SENSORPANEL-0-16.13, U11.5 (+IN_B)
unnamed: R43.2, R95.1, U11.6 (-IN_B)
unnamed: R41.1, SENSORPANEL-0-16.14, U11.3 (+IN_A)
unnamed: R96.2, U12.1 (OUT_A), U14.4 (Y7)
unnamed: R97.2, U12.7 (OUT_B), U14.2 (Y6)
unnamed: R46.1, SENSORPANEL-0-16.15, U12.5 (+IN_B)
unnamed: R45.1, SENSORPANEL-0-16.16, U12.3 (+IN_A)
unnamed: R2.2, U15.1 (OUT_A), U23.14 (Y1)
unnamed: IC2.15 (QA), U13.11 (S0), U14.11 (S0), U23.11 (S0), U24.11 (S0)
unnamed: IC2.1 (QB), U13.10 (S1), U14.10 (S1), U23.10 (S1), U24.10 (S1)
unnamed: IC2.2 (QC), U13.9 (S2), U14.9 (S2), U23.9 (S2), U24.9 (S2)
unnamed: IC2.3 (QD), U13.6 (~E)
unnamed: IC2.4 (QE), U14.6 (~E)
unnamed: R5.2, U15.7 (OUT_B), U23.13 (Y0)
unnamed: R49.1, SENSORPANEL-16-31.2, U15.3 (+IN_A)
unnamed: R50.1, SENSORPANEL-16-31.1, U15.5 (+IN_B)
unnamed: R7.2, U16.1 (OUT_A), U23.12 (Y3)
unnamed: R9.2, U16.7 (OUT_B), U23.15 (Y2)
unnamed: R53.1, SENSORPANEL-16-31.4, U16.3 (+IN_A)
unnamed: R54.1, SENSORPANEL-16-31.3, U16.5 (+IN_B)
unnamed: R10.2, U17.1 (OUT_A), U23.5 (Y5)
unnamed: R13.2, U17.7 (OUT_B), U23.1 (Y4)
unnamed: R57.1, SENSORPANEL-16-31.6, U17.3 (+IN_A)
unnamed: R58.1, SENSORPANEL-16-31.5, U17.5 (+IN_B)
unnamed: R15.2, U18.1 (OUT_A), U23.4 (Y7)
unnamed: R51.2, U18.7 (OUT_B), U23.2 (Y6)
unnamed: R62.1, SENSORPANEL-16-31.7, U18.5 (+IN_B)
unnamed: R61.1, SENSORPANEL-16-31.8, U18.3 (+IN_A)
unnamed: R55.2, U19.1 (OUT_A), U24.14 (Y1)
unnamed: R59.2, U19.7 (OUT_B), U24.13 (Y0)
unnamed: R66.1, SENSORPANEL-16-31.9, U19.5 (+IN_B)
unnamed: R65.1, SENSORPANEL-16-31.10, U19.3 (+IN_A)
unnamed: R63.2, U20.1 (OUT_A), U24.12 (Y3)
unnamed: R67.2, U20.7 (OUT_B), U24.15 (Y2)
unnamed: R70.1, SENSORPANEL-16-31.11, U20.5 (+IN_B)
unnamed: R69.1, SENSORPANEL-16-31.12, U20.3 (+IN_A)
unnamed: R71.2, U21.1 (OUT_A), U24.5 (Y5)
unnamed: R75.2, U21.7 (OUT_B), U24.1 (Y4)
unnamed: R74.1, SENSORPANEL-16-31.13, U21.5 (+IN_B)
unnamed: R73.1, SENSORPANEL-16-31.14, U21.3 (+IN_A)
unnamed: R80.2, U22.1 (OUT_A), U24.4 (Y7)
unnamed: R81.2, U22.7 (OUT_B), U24.2 (Y6)
unnamed: R78.1, SENSORPANEL-16-31.15, U22.5 (+IN_B)
unnamed: R77.1, SENSORPANEL-16-31.16, U22.3 (+IN_A)
unnamed: IC2.5 (QF), U23.6 (~E)
unnamed: IC2.6 (QG), U24.6 (~E)
unnamed: IC2.12 (RCK), MAINBOARD.3
SHIFT_CLK: IC2.11 (SCK), MAINBOARD.2
SHIFT_SER: IC2.14 (SER), MAINBOARD.1

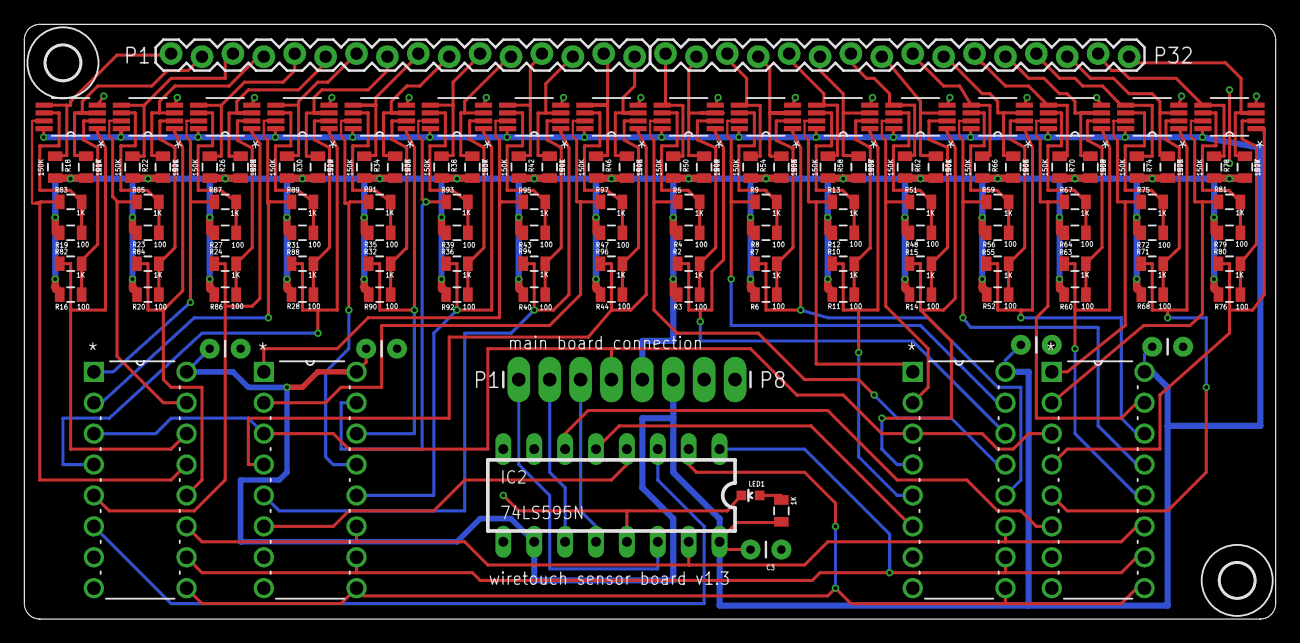
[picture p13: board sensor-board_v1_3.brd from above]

Board: 2 copper layers, 102.9 x 48.9 mm, 129 parts (0 on the bottom side), 111 nets.

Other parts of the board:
U$1, U$2: 2,8

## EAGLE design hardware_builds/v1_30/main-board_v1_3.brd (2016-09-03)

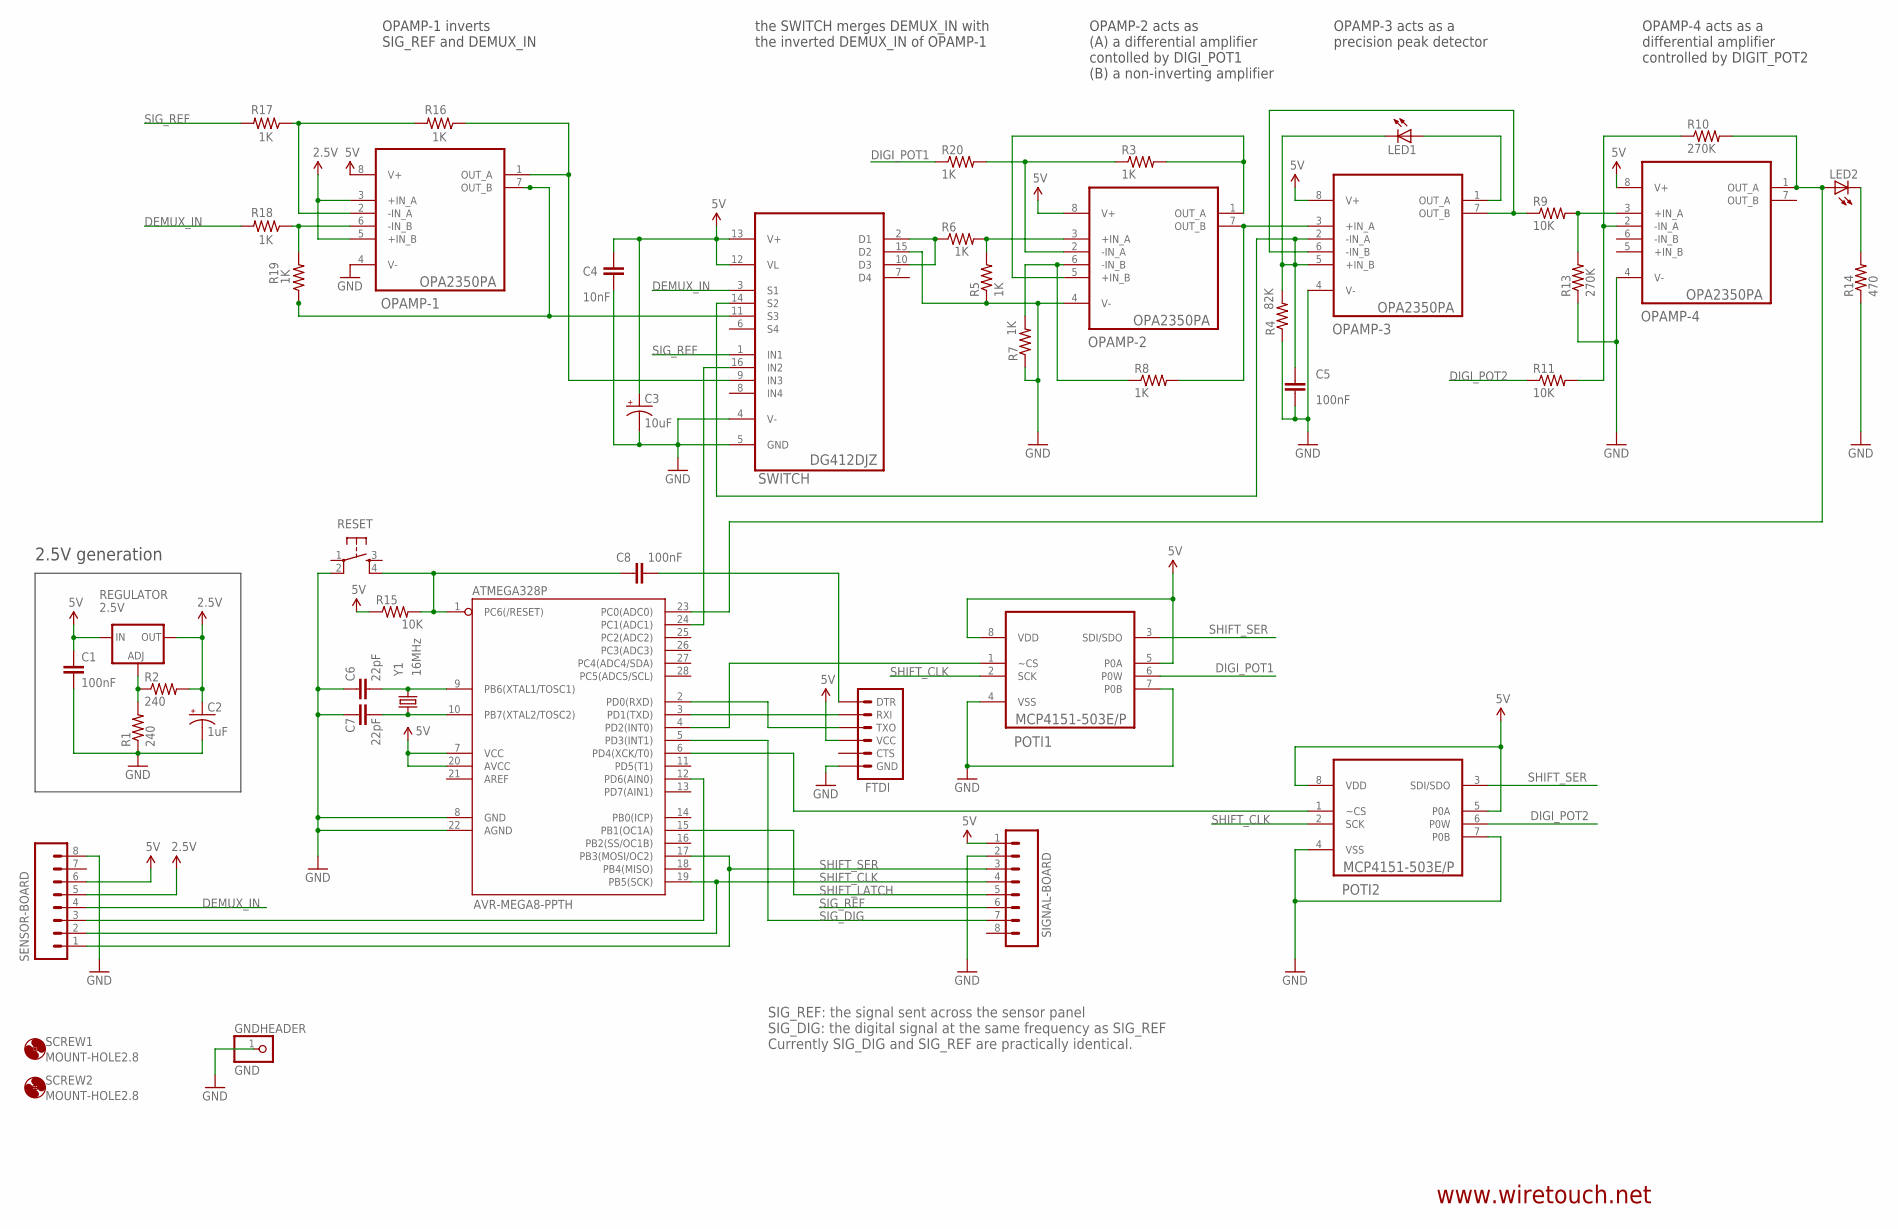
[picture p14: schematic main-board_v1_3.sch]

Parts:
ATMEGA328P: AVR-MEGA8-PPTH; DIL28-3
C1, C5: 100nF; CAP-PTH-SMALL
C2: 1uF; CPOL-RADIAL-10UF-25V
C3: 10uF; CPOL-RADIAL-10UF-25V
C4: 10nF; CAP-PTH-SMALL
C6, C7: 22pF; CAP-PTH-SMALL2
C8: 100nF; CAP-PTH-SMALL2
FTDI: ARDUINO_SERIAL_PROGRAMLONGPADS; 1X06_LONGPADS
GNDHEADER: GND; 1X01
LED1: LED3MM
LED2: LED5MM
OPAMP-1, OPAMP-2, OPAMP-3, OPAMP-4: OPA2350PA; DIP254P762X508-8
POTI1, POTI2: MCP4151-503E/P; DIP254P762X533-8
R1, R2: 240; AXIAL-0.3
R3, R5, R6, R7, R8, R16, R17, R18, R19, R20: 1K; AXIAL-0.3
R4: 82K; AXIAL-0.3
R9, R11, R15: 10K; AXIAL-0.3
R10, R13: 270K; AXIAL-0.3
R14: 470; AXIAL-0.3
REGULATOR: 2.5V; TO220-ADJ
RESET: Omron B3F momentary on switch; TACTILE-PTH
SCREW1, SCREW2: MOUNT-HOLE2.8; 2,8
SENSOR-BOARD: M08LONGPADS; 1X08_LONGPADS
SIGNAL-BOARD: M08LONGPADS; 1X08_LONGPADS
SWITCH: DG412DJZ; DIP254P762X533-16
Y1: 16MHz; HC49US

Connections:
2.8V: C2.1 (+), OPAMP-1.3 (+IN_A), OPAMP-1.5 (+IN_B), R2.P$2 (2), REGULATOR.OUT, SENSOR-BOARD.5
5V: ATMEGA328P.7 (VCC), ATMEGA328P.20 (AVCC), C1.1, C3.1 (+), C4.1, FTDI.4 (VCC), OPAMP-1.8 (V+), OPAMP-2.8 (V+), OPAMP-3.8 (V+), OPAMP-4.8 (V+), POTI1.5 (P0A), POTI1.8 (VDD), POTI2.5 (P0A), POTI2.8 (VDD), R15.P$1 (1), REGULATOR.IN, SENSOR-BOARD.6, SIGNAL-BOARD.1, SWITCH.12 (VL), SWITCH.13 (V+)
DEMUX_IN: R18.P$2 (2), SENSOR-BOARD.4, SWITCH.3 (S1)
DIGI_POT1: POTI1.6 (P0W), R20.P$1 (1)
DIGI_POT2: POTI2.6 (P0W), R11.P$1 (1)
GND: ATMEGA328P.8 (GND), ATMEGA328P.22 (AGND), C1.2, C2.2 (-), C3.2 (-), C4.2, C5.2, C6.1, C7.1, FTDI.6 (GND), GNDHEADER.1, OPAMP-1.4 (V-), OPAMP-2.4 (V-), OPAMP-3.4 (V-), OPAMP-4.4 (V-), POTI1.4 (VSS), POTI1.7 (P0B), POTI2.4 (VSS), POTI2.7 (P0B), R1.P$1 (1), R4.P$1 (1), R5.P$1 (1), R7.P$1 (1), R13.P$1 (1), R14.P$1 (1), RESET.2, SENSOR-BOARD.8, SIGNAL-BOARD.2, SWITCH.4 (V-), SWITCH.5 (GND), SWITCH.15 (D2)
unnamed: R6.P$1 (1), SWITCH.2 (D1), SWITCH.10 (D3)
unnamed: OPAMP-2.1 (OUT_A), OPAMP-2.5 (+IN_B), R3.P$2 (2)
unnamed: R1.P$2 (2), R2.P$1 (1), REGULATOR.ADJ
unnamed: OPAMP-2.2 (-IN_A), R3.P$1 (1), R20.P$2 (2)
unnamed: OPAMP-2.3 (+IN_A), R5.P$2 (2), R6.P$2 (2)
unnamed: OPAMP-2.6 (-IN_B), R7.P$2 (2), R8.P$1 (1)
unnamed: OPAMP-4.2 (-IN_A), R10.P$1 (1), R11.P$2 (2)
unnamed: ATMEGA328P.24 (PC1(ADC1)), SWITCH.16 (IN2)
unnamed: LED1.A, OPAMP-3.1 (OUT_A)
unnamed: OPAMP-2.7 (OUT_B), OPAMP-3.3 (+IN_A), R8.P$2 (2)
unnamed: C5.1, LED1.K (C), OPAMP-3.2 (-IN_A), OPAMP-3.5 (+IN_B), R4.P$2 (2), SWITCH.14 (S2)
unnamed: OPAMP-3.6 (-IN_B), OPAMP-3.7 (OUT_B), R9.P$1 (1)
unnamed: OPAMP-4.3 (+IN_A), R9.P$2 (2), R13.P$2 (2)
unnamed: ATMEGA328P.23 (PC0(ADC0)), LED2.A, OPAMP-4.1 (OUT_A), R10.P$2 (2)
unnamed: ATMEGA328P.6 (PD4(XCK/T0)), POTI2.1 (~CS)
unnamed: OPAMP-1.6 (-IN_B), R18.P$1 (1), R19.P$2 (2)
unnamed: LED2.K (C), R14.P$2 (2)
unnamed: ATMEGA328P.9 (PB6(XTAL1/TOSC1)), C6.2, Y1.2
unnamed: ATMEGA328P.10 (PB7(XTAL2/TOSC2)), C7.2, Y1.1
unnamed: ATMEGA328P.1 (PC6(/RESET)), C8.1, R15.P$2 (2), RESET.4
unnamed: ATMEGA328P.3 (PD1(TXD)), FTDI.2 (RXI)
unnamed: ATMEGA328P.2 (PD0(RXD)), FTDI.3 (TXO)
unnamed: C8.2, FTDI.1 (DTR)
unnamed: OPAMP-1.1 (OUT_A), R16.P$1 (1), SWITCH.9 (IN3)
unnamed: OPAMP-1.2 (-IN_A), R16.P$2 (2), R17.P$1 (1)
unnamed: OPAMP-1.7 (OUT_B), R19.P$1 (1), SWITCH.11 (S3)
unnamed: ATMEGA328P.4 (PD2(INT0)), POTI1.1 (~CS)
unnamed: ATMEGA328P.12 (PD6(AIN0)), SENSOR-BOARD.3
SHIFT_CLK: ATMEGA328P.19 (PB5(SCK)), POTI1.2 (SCK), POTI2.2 (SCK), SENSOR-BOARD.2, SIGNAL-BOARD.4
SHIFT_LATCH: ATMEGA328P.15 (PB1(OC1A)), SIGNAL-BOARD.5
SHIFT_SER: ATMEGA328P.17 (PB3(MOSI/OC2)), POTI1.3 (SDI/SDO), POTI2.3 (SDI/SDO), SENSOR-BOARD.1, SIGNAL-BOARD.3
SIG_DIG: ATMEGA328P.5 (PD3(INT1)), SIGNAL-BOARD.7
SIG_REF: R17.P$2 (2), SIGNAL-BOARD.6, SWITCH.1 (IN1)

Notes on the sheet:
2.5V generation
www.wiretouch.net
SIG_REF: the signal sent across the sensor panel SIG_DIG: the digital signal at the same frequency as SIG_REF Currently SIG_DIG and SIG_REF are practically identical.
OPAMP-3 acts as a precision peak detector
OPAMP-4 acts as a differential amplifier controlled by DIGIT_POT2
OPAMP-2 acts as (A) a differential amplifier contolled by DIGI_POT1 (B) a non-inverting amplifier
OPAMP-1 inverts SIG_REF and DEMUX_IN
the SWITCH merges DEMUX_IN with the inverted DEMUX_IN of OPAMP-1

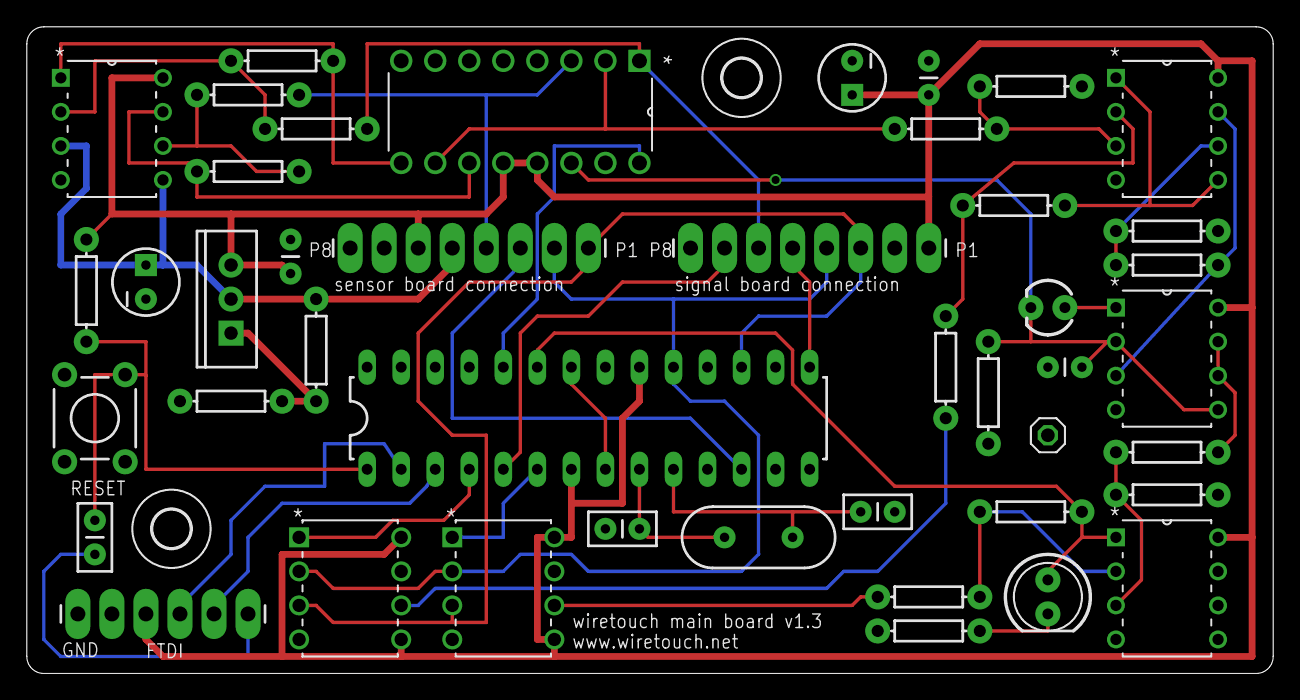
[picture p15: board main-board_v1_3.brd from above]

Board: 2 copper layers, 93.0 x 48.3 mm, 46 parts (0 on the bottom side), 39 nets.

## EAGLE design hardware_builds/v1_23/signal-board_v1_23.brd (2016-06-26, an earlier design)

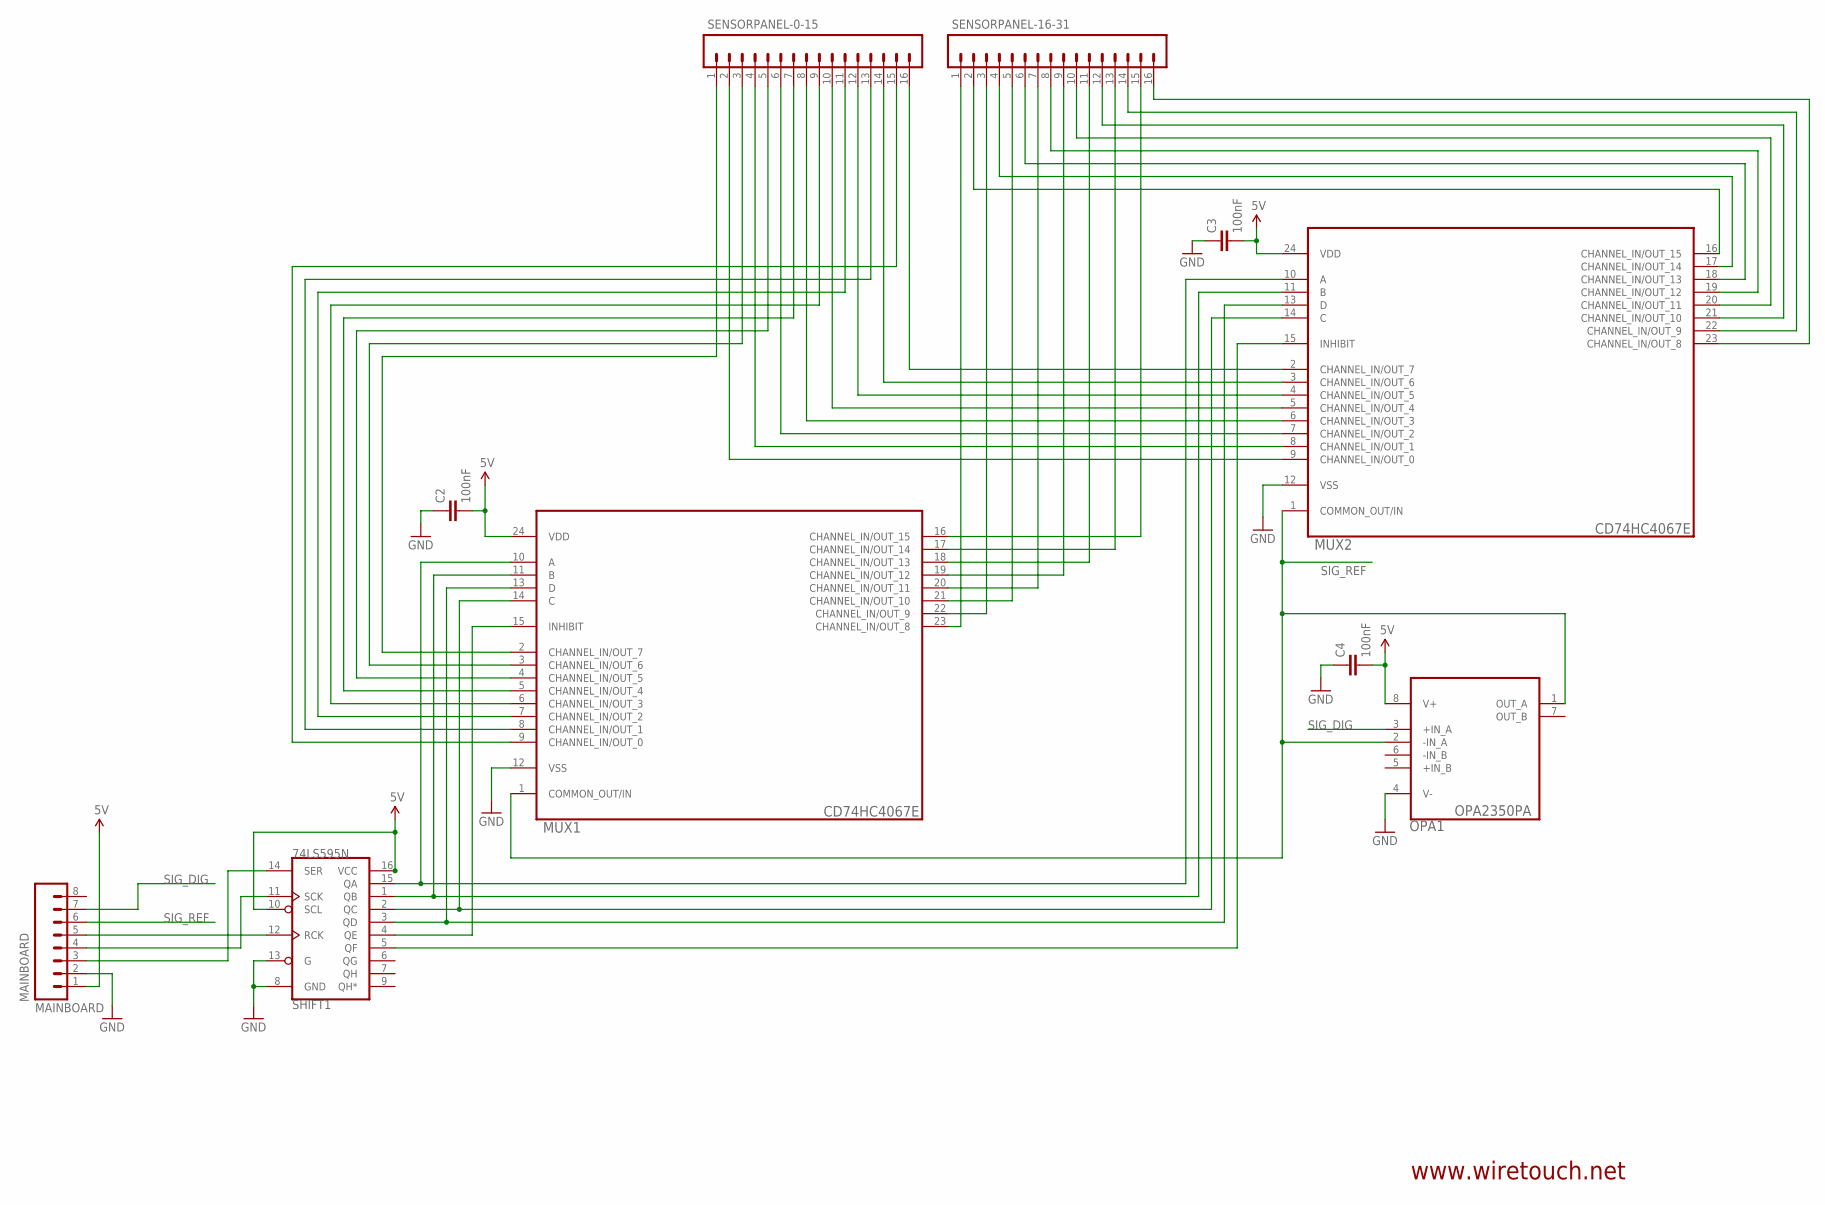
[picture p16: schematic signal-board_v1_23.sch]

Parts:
C2, C3, C4: 100nF; CAP-PTH-SMALL
MAINBOARD: MAINBOARD; 1X08_LONGPADS
MUX1, MUX2: CD74HC4067E; PDIP24-WIDE-CD74HC4067E
OPA1: OPA2350PA; DIP254P762X508-8
SENSORPANEL-0-15, SENSORPANEL-16-31: M16LOCK_LONGPADS; 1X16_LOCK_LONGPADS
SHIFT1: 74LS595N; DIL16

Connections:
5V: C2.2, C3.2, C4.2, MAINBOARD.1, MUX1.24 (VDD), MUX2.24 (VDD), OPA1.8 (V+), SHIFT1.10 (SCL), SHIFT1.16 (VCC)
GND: C2.1, C3.1, C4.1, MAINBOARD.2, MUX1.12 (VSS), MUX2.12 (VSS), OPA1.4 (V-), SHIFT1.8 (GND), SHIFT1.13 (G)
unnamed: MUX1.2 (CHANNEL_IN/OUT_7), SENSORPANEL-0-15.1
unnamed: MUX1.3 (CHANNEL_IN/OUT_6), SENSORPANEL-0-15.3
unnamed: MUX1.4 (CHANNEL_IN/OUT_5), SENSORPANEL-0-15.5
unnamed: MUX1.5 (CHANNEL_IN/OUT_4), SENSORPANEL-0-15.7
unnamed: MUX1.6 (CHANNEL_IN/OUT_3), SENSORPANEL-0-15.9
unnamed: MUX1.7 (CHANNEL_IN/OUT_2), SENSORPANEL-0-15.11
unnamed: MUX1.8 (CHANNEL_IN/OUT_1), SENSORPANEL-0-15.13
unnamed: MUX1.9 (CHANNEL_IN/OUT_0), SENSORPANEL-0-15.15
unnamed: MUX1.23 (CHANNEL_IN/OUT_8), SENSORPANEL-16-31.1
unnamed: MUX1.22 (CHANNEL_IN/OUT_9), SENSORPANEL-16-31.3
unnamed: MUX1.21 (CHANNEL_IN/OUT_10), SENSORPANEL-16-31.5
unnamed: MUX1.20 (CHANNEL_IN/OUT_11), SENSORPANEL-16-31.7
unnamed: MUX1.19 (CHANNEL_IN/OUT_12), SENSORPANEL-16-31.9
unnamed: MUX1.18 (CHANNEL_IN/OUT_13), SENSORPANEL-16-31.11
unnamed: MUX1.17 (CHANNEL_IN/OUT_14), SENSORPANEL-16-31.13
unnamed: MUX1.16 (CHANNEL_IN/OUT_15), SENSORPANEL-16-31.15
unnamed: MUX2.9 (CHANNEL_IN/OUT_0), SENSORPANEL-0-15.2
unnamed: MUX2.8 (CHANNEL_IN/OUT_1), SENSORPANEL-0-15.4
unnamed: MUX2.7 (CHANNEL_IN/OUT_2), SENSORPANEL-0-15.6
unnamed: MUX2.6 (CHANNEL_IN/OUT_3), SENSORPANEL-0-15.8
unnamed: MUX2.5 (CHANNEL_IN/OUT_4), SENSORPANEL-0-15.10
unnamed: MUX2.4 (CHANNEL_IN/OUT_5), SENSORPANEL-0-15.12
unnamed: MUX2.3 (CHANNEL_IN/OUT_6), SENSORPANEL-0-15.14
unnamed: MUX2.2 (CHANNEL_IN/OUT_7), SENSORPANEL-0-15.16
unnamed: MUX2.16 (CHANNEL_IN/OUT_15), SENSORPANEL-16-31.2
unnamed: MUX2.17 (CHANNEL_IN/OUT_14), SENSORPANEL-16-31.4
unnamed: MUX2.18 (CHANNEL_IN/OUT_13), SENSORPANEL-16-31.6
unnamed: MUX2.19 (CHANNEL_IN/OUT_12), SENSORPANEL-16-31.8
unnamed: MUX2.20 (CHANNEL_IN/OUT_11), SENSORPANEL-16-31.10
unnamed: MUX2.21 (CHANNEL_IN/OUT_10), SENSORPANEL-16-31.12
unnamed: MUX2.22 (CHANNEL_IN/OUT_9), SENSORPANEL-16-31.14
unnamed: MUX2.23 (CHANNEL_IN/OUT_8), SENSORPANEL-16-31.16
unnamed: MUX1.11 (B), MUX2.11 (B), SHIFT1.1 (QB)
unnamed: MUX1.10 (A), MUX2.10 (A), SHIFT1.15 (QA)
unnamed: MUX1.14 (C), MUX2.14 (C), SHIFT1.2 (QC)
unnamed: MAINBOARD.3, SHIFT1.14 (SER)
unnamed: MUX1.15 (INHIBIT), SHIFT1.4 (QE)
unnamed: MUX2.15 (INHIBIT), SHIFT1.5 (QF)
unnamed: MAINBOARD.4, SHIFT1.11 (SCK)
unnamed: MUX1.13 (D), MUX2.13 (D), SHIFT1.3 (QD)
unnamed: MAINBOARD.5, SHIFT1.12 (RCK)
SIG_DIG: MAINBOARD.7, OPA1.3 (+IN_A)
SIG_REF: MAINBOARD.6, MUX1.1 (COMMON_OUT/IN), MUX2.1 (COMMON_OUT/IN), OPA1.1 (OUT_A), OPA1.2 (-IN_A)

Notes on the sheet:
www.wiretouch.net

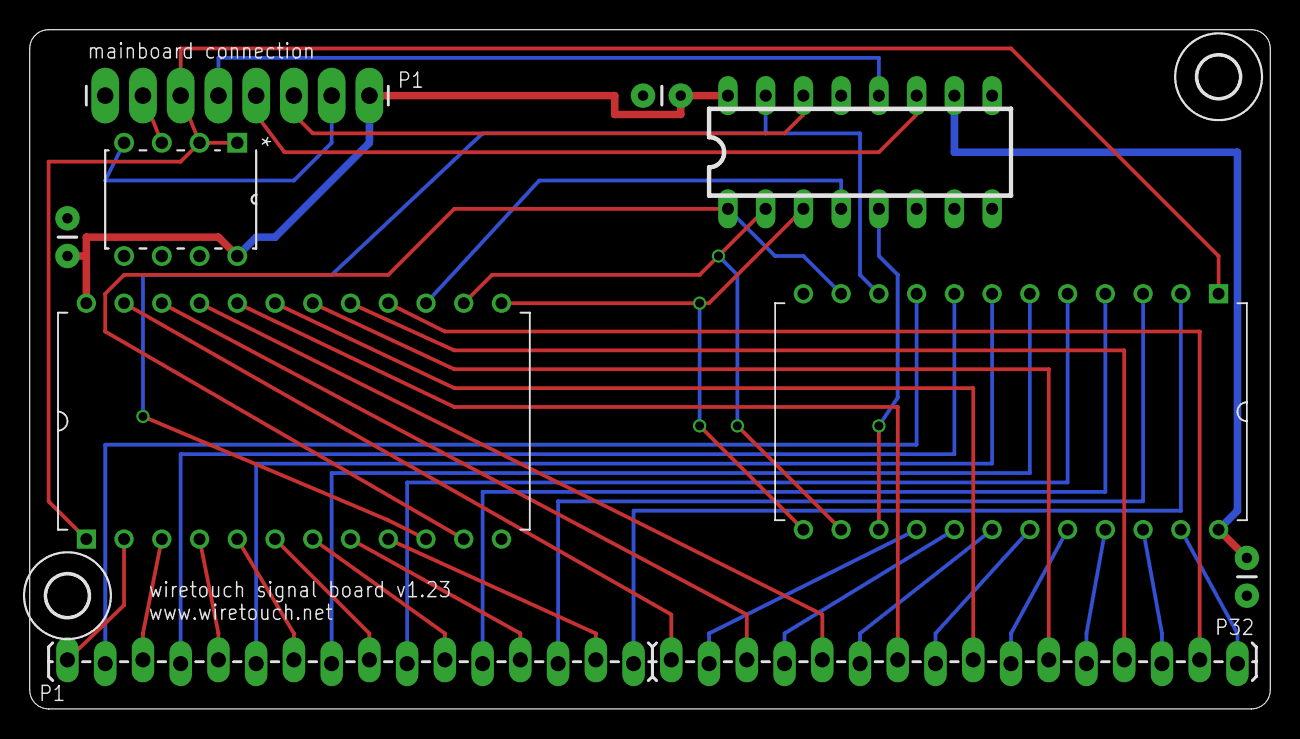
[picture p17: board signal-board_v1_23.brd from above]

Board: 2 copper layers, 83.5 x 45.7 mm, 12 parts (0 on the bottom side), 45 nets.

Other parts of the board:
U$6, U$7: 2,8

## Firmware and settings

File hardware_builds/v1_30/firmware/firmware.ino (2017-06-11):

/* Wiretouch: an open capacitive multi-touch tracker
   Copyright (C) 2011-2013 Georg Kaindl and Armin Wagner

   This file is part of WireTouch

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
   You should have received a copy of the GNU General Public License
   along with WireTouch. If not, see <http://www.gnu.org/licenses/>.
*/

#include <SPI.h>

#define FIRMWARE_VERSION    "1.0b6"

#define SERIAL_BAUD         115200  // set to 500000 when using the patched FTDI driver
#define SER_BUF_SIZE        256     // serial buffer for sending
#define IBUF_LEN            12      // serial buffer for incoming commands

#define DEFAULT_MEASURE_DELAY       8
#define HALFWAVE_POT_VALUE          246
#define OUTPUT_AMP_POT_VALUE        37
#define OUTPUT_AMP_POT_TUNE_DEFAULT 8
#define WAVE_FREQUENCY              18  

#define CALIB_PASSES_BASE               128
#define CALIB_PASSES_AT_EACH_CROSSPOINT 16
#define CALIB_THRESHOLD                 500
#define CALIB_THRESHOLD2                1005
#define CALIB_OUTPUT_BLIND_DELTA        4

#define ORDER_MEASURE_UNORDERED   0
#define PRINT_BINARY              1 // set to 0 if you want to debug via serial monitor
#define measure                   measure_with_atmega_adc

#ifndef cbi
#define cbi(sfr, bit) (_SFR_BYTE(sfr) &= ~_BV(bit))
#endif
#ifndef sbi
#define sbi(sfr, bit) (_SFR_BYTE(sfr) |= _BV(bit))
#endif

const byte signalboardWires = 32;
const byte sensorboardWires = 22;

static uint8_t sbuf[SER_BUF_SIZE + 1];
static uint16_t sbufpos = 0;

static byte halfwavePotBase   = HALFWAVE_POT_VALUE;
static byte outputAmpPotBase  = OUTPUT_AMP_POT_VALUE;
static byte waveFrequency     = WAVE_FREQUENCY;
static uint16_t measureDelay  = DEFAULT_MEASURE_DELAY;

static byte outputAmpPotTune[((signalboardWires * sensorboardWires) >> 1) + 1];

static byte isRunning;

void setup()
{
  Serial.begin(SERIAL_BAUD);

  // set prescale to 16
  cbi(ADCSRA, ADPS2);
  sbi(ADCSRA, ADPS1);
  cbi(ADCSRA, ADPS0);

  pinMode(2, OUTPUT);     // CS for SPI pot 1 (halfwave splitting)        PD2
  pinMode(3, OUTPUT);     // reference signal OUT                         PD3
  pinMode(4, OUTPUT);     // CS for SPI pot 2 (output amplifier)          PD4
  pinMode(6, OUTPUT);     // horizontal lines (sensor) shift reg latch    PD6
  pinMode(9, OUTPUT);     // vertical lines (signal) shift reg latch      PB1
  pinMode(A1, OUTPUT);    // maximum "sample and hold" RESET switch       PC1

  SPI.setBitOrder(MSBFIRST);
  SPI.setClockDivider(SPI_CLOCK_DIV2);
  SPI.setDataMode(SPI_MODE0);
  SPI.begin();

  PORTD |= (1 << 2) | (1 << 4);

  set_wave_frequency(waveFrequency);
  set_halfwave_pot(halfwavePotBase);
  reset_output_amp_tuning();
}

void reset_output_amp_tuning()
{
  for (int i = 0; i < sizeof(outputAmpPotTune); i++)
    outputAmpPotTune[i] = (OUTPUT_AMP_POT_TUNE_DEFAULT) | (OUTPUT_AMP_POT_TUNE_DEFAULT << 4);
}

byte output_amp_tuning_for_point(byte x, byte y)
{
  uint16_t pt = y * signalboardWires + x;
  return (outputAmpPotTune[pt >> 1] >> (4 * (pt & 1))) & 0xf;
}

void set_output_amp_tuning_for_point(byte x, byte y, byte val)
{
  uint16_t pt = y * signalboardWires + x;
  outputAmpPotTune[pt >> 1] =
    (outputAmpPotTune[pt >> 1] & ((pt & 1) ? 0x0f : 0xf0)) |
    ((val & 0x0f) << (4 * (pt & 1)));
}

void set_wave_frequency(byte freq)
{
  TCCR2A = B00100011;
  TCCR2B = B11001;
  OCR2A = freq << 1;
  OCR2B = freq;
}

inline void muxSPI(byte output, byte vertical, byte off)
{
  if (vertical)
    PORTB &= ~(1 << 1);
  else
    PORTD &= ~(1 << 6);

  byte bits = 0;

  if (vertical) {
    if (off)
      bits = 0xff;
    else {
      if (output < 16) {
        bits = (1 << 4);
      }
      else {
        bits = (1 << 5);
      }
      bits |= output % 16;
    }
  } else {
    if (off)
      bits = 0xff;
    else
      bits = ((~(1 << ((output / 8)))) << 3) | (output % 8);
  }

  SPDR = bits;
  while (!(SPSR & _BV(SPIF)));

  if (vertical)
    PORTB |= (1 << 1);
  else
    PORTD |= (1 << 6);
}

inline void set_halfwave_pot(uint16_t value)
{
  PORTD &= ~(1 << 2);
  SPDR = (value >> 8) & 0xff;
  while (!(SPSR & _BV(SPIF)));
  SPDR = (value & 0xff);
  while (!(SPSR & _BV(SPIF)));
  PORTD |= (1 << 2);
}

inline void set_output_amp_pot(uint16_t value)
{
  PORTD &= ~(1 << 4);
  SPDR = (value >> 8) & 0xff;
  while (!(SPSR & _BV(SPIF)));
  SPDR = (value & 0xff);
  while (!(SPSR & _BV(SPIF)));
  PORTD |= (1 << 4);
}

inline unsigned int measure_with_atmega_adc()
{
  return analogRead(0);
}

inline void send_packed10(uint16_t w16, byte flush_all)
{
  static byte p = 0;
  static uint16_t d16 = 0;

  d16 |= (w16 << p);
  p += 10;

  while (p >= 8) {
    sbuf[sbufpos++] = (d16 & 0xff);
    p -= 8;
    d16 >>= 8;
  }

  if (flush_all && p > 0) {
    sbuf[sbufpos++] = (d16 & 0xff);
    p = 0;
    d16 = 0;
  }

  if (flush_all || sbufpos >= SER_BUF_SIZE) {
    Serial.write(sbuf, sbufpos);
    Serial.flush();
    sbufpos = 0;
  }
}

inline void map_coords(uint16_t x, uint16_t y, uint16_t* mx, uint16_t* my)
{
    #if ORDER_MEASURE_UNORDERED
    uint16_t a = x * sensorboardWires + y;
    uint16_t b = (59 * a + 13) % (sensorboardWires * signalboardWires);

    *mx = b / sensorboardWires;
    *my = b - (*mx) * ((uint16_t)sensorboardWires);
    #else
    *mx = x;
    *my = y;
    #endif
}

uint16_t measure_one(uint16_t x, uint16_t y)
{
  uint16_t xx, yy, sample;

  map_coords(x, y, &xx, &yy);

  set_output_amp_pot(outputAmpPotBase + output_amp_tuning_for_point(xx, yy));

  muxSPI(xx, 1, 0);
  muxSPI(yy, 0, 0);

  PORTC &= ~(1 << 1);

  delayMicroseconds(measureDelay);

  sample = measure_with_atmega_adc();

  PORTC |= 1 << 1;

  return sample;
}

uint16_t measure_one_avg(uint16_t x, uint16_t y, uint16_t passes)
{
  uint16_t p = passes;
  uint32_t avg_sample = 0;

  while (p-- > 0)
    avg_sample += measure_one(x, y);

  return (avg_sample / passes);
}

void auto_tune_output_amp()
{
  uint16_t targetValue = 0;
  byte mid_x = signalboardWires >> 1, mid_y = sensorboardWires >> 1;
  uint16_t xx, yy;

  for (uint16_t oabase = 255; oabase > 0; oabase--) {
    outputAmpPotBase = oabase;

    set_output_amp_pot(oabase);

    map_coords(mid_x, mid_y, &xx, &yy);

    // Sample the circuit output at a cross point roughly at the middle of the sensor panel.
    // Find the hightest possible value at which the measurement still exhibits some noise.
    // We will use this value for the base output amplification
    if ((targetValue = measure_one_avg(xx, yy, CALIB_PASSES_BASE)) > CALIB_THRESHOLD)
      break;
  }

  for (uint16_t k = 0; k < signalboardWires; k++) {
    for (uint16_t l = 0; l < sensorboardWires; l++) {
      uint16_t minDiff = 0xffff, tune_val = 0;

      map_coords(k, l, &xx, &yy);

      for (byte amp_tune = 0; amp_tune < 16; amp_tune++) {
        set_output_amp_tuning_for_point(xx, yy, amp_tune);

        uint16_t val = measure_one_avg(k, l, CALIB_PASSES_AT_EACH_CROSSPOINT);
        uint16_t diff = (uint16_t)abs((int)val - (int)targetValue);

        if (diff < minDiff) {
          minDiff = diff;
          tune_val = amp_tune;
        }
      }
      set_output_amp_tuning_for_point(xx, yy, tune_val);
    }
  }
  // TODO: test
  for (uint16_t oabase = outputAmpPotBase; oabase > 0; oabase--) {
    outputAmpPotBase = oabase;

    set_output_amp_pot(oabase);

    map_coords(mid_x, mid_y, &xx, &yy);

    if ((targetValue = measure_one_avg(xx, yy, CALIB_PASSES_BASE)) > CALIB_THRESHOLD2) {
      outputAmpPotBase -= CALIB_OUTPUT_BLIND_DELTA;
      break;
    }
  }
}

void print_configuration_info()
{
  char buf[128] = {0};
  sprintf(buf, "{ \"halfwave_amp\":\"%d\", \"output_amp\":\"%d\", \"version\":\"%s\"}",
          halfwavePotBase, outputAmpPotBase, FIRMWARE_VERSION);
  Serial.println(buf);
  /* 
    for (uint16_t k = 0; k < signalboardWires; k++) {
      for (uint16_t l = 0; l < sensorboardWires; l++) {
        sprintf(buf, "\"tune_%d_%d\":\"%d\",",
        k, l, output_amp_tuning_for_point(k, l));
        Serial.print(buf);
      }
    }
    Serial.print(buf);
  */
  Serial.println("}");
}

void process_cmd(char* cmd)
{
  switch (*cmd++) {
    case 'e': {
        byte x = 0, y = 0, value = 0;

        while (',' != *cmd)
          x = x * 10 + (*cmd++ - '0');

        cmd++;    // skip the ,

        while (',' != *cmd)
          y = y * 10 + (*cmd++ - '0');

        cmd++;    // skip the ,

        while ('\n' != *cmd)
          value = value * 10 + (*cmd++ - '0');

        set_output_amp_tuning_for_point(x, y, value);

        break;
      }

    case 'o': {
        byte value = 0;

        while ('\n' != *cmd)
          value = value * 10 + (*cmd++ - '0');

        outputAmpPotBase = value;

        break;
      }

    case 'h': {
        byte value = 0;

        while ('\n' != *cmd)
          value = value * 10 + (*cmd++ - '0');

        set_halfwave_pot((halfwavePotBase = value));

        break;
      }

    case 'd': {
        uint16_t value = 0;

        while ('\n' != *cmd)
          value = value * 10 + (*cmd++ - '0');

        measureDelay = value;

        break;
      }

    case 'f': {
        uint16_t value = 0;

        while ('\n' != *cmd)
          value = value * 10 + (*cmd++ - '0');

        set_wave_frequency(waveFrequency = value);

        break;
      }

    case 's': {
        isRunning = 1;
        break;
      }

    case 'x': {
        isRunning = 0;  // stop sending measurement data
        Serial.flush(); // wait for the transmission of the outgoing data to complete
        break;
      }

    case 'c': {
        reset_output_amp_tuning();
        auto_tune_output_amp();
        break;
      }

    case 'r': {
        reset_output_amp_tuning();
        break;
      }

    case 'i': {
        print_configuration_info();
        break;
      }

    default:
      break;
  }
}

void loop()
{
  static byte ibuf_pos = 0;
  static char ibuf[IBUF_LEN];
  uint16_t sample;

  while (Serial.available()) {
    byte c = Serial.read();

    if (ibuf_pos < IBUF_LEN) {
      ibuf[ibuf_pos++] = c;
    } else
      ibuf_pos = 0;

    if ('\n' == c) {
      process_cmd(ibuf);
      ibuf_pos = 0;
    }
  }

  if (!isRunning)
    return;

  int cnt = 0;
  for (uint16_t k = 0; k < signalboardWires; k++) {
    for (uint16_t l = 0; l < sensorboardWires; l++) {
      sample = measure_one(k, l);

      cnt++;
#if PRINT_BINARY
      send_packed10(sample, (cnt >= signalboardWires * sensorboardWires));
      if (cnt >= signalboardWires * sensorboardWires) cnt = 0;
#else
      Serial.print(sample, DEC);
      Serial.print(",");
#endif
    }
  }

#if !PRINT_BINARY
  Serial.print(" ");
#endif
}

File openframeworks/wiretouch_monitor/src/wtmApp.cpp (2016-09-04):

/* WireTouch: an open capacitive multi-touch tracker
 * Copyright (C) 2011-2013 Georg Kaindl and Armin Wagner
 *
 * This file is part of WireTouch
 *
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
 * You should have received a copy of the GNU General Public License
 * along with WireTouch. If not, see <http://www.gnu.org/licenses/>.
 */

#include "wtmApp.h"
#include "cJSON.h"

//--------------------------------------------------------------
void wtmApp::setup() {
    ofSetVerticalSync(true);
	ofBackground(0);
	ofSetLogLevel(OF_LOG_VERBOSE);
    
    this->signalWires = SIGNALWIRES;
    this->sensorWires = SENSORWIRES;
    
    this->inputGamma = 1;
    
    this->bytesPerFrame = (signalWires*sensorWires*10)/8;
    this->recvBuffer = (unsigned char*) malloc(this->bytesPerFrame * sizeof(unsigned char));
    this->calibrationResultsString.clear();
    this->capGridValues = (uint16_t*) malloc(signalWires * sensorWires * sizeof(uint16_t));
    
    this->interpolator = NULL;
    this->interpolatorType = wtmInterpolatorTypeCatmullRom;
    this->interpolatorUpsampleX = 8;
    this->interpolatorUpsampleY = 8;
    this->updateInterpolator();
    
    this->blobTracker = new wtmBlobTracker();

    this->state = wtmAppStateNoSerialConnection;
    this->lastWindowResizeTime = -1.0;
    this->serialOpenTime = 0;
    this->bNewDataToShow = false;
    
    // see wtmApp_Gui.cpp
    initGUI();
    loadSettings();
    
    ofLogNotice() << "starting up local TUIO Server.";
    this->tuioServer = new wtmTuioServer();
    this->tuioServer->start("127.0.0.1", 3333);
}

//--------------------------------------------------------------
void wtmApp::update() {
    float now = ofGetElapsedTimef();

    // window resizing
    if (this->lastWindowResizeTime > 0) {
        if ((now - this->lastWindowResizeTime) <.5)
            return;
        else if (now - this->lastWindowResizeTime > .5) {
            this->lastWindowResizeTime = -1.0;
            
            if (wtmAppStateReceivingTouches == this->state) {
                this->stopSensor();
                ofSleepMillis(100);
                this->startSensor();
            }
        }
    }
    
    // serial communication
    // the application has 5 different states
    // wtmAppStateNoSerialConnection:           The serial connection has not been initialized yet.
    // wtmAppStateStartWhenSerialInitalized:    The serial connection is opening. Changes into wtmAppStateReceivingTouches.
    // wtmAppStateReceivingTouches:             The application continously retrieves touch data.
    // wtmAppStateIdle:                         The user pressed STOP.
    // wtmAppStateReceivingSettings:            The user pressed CALIBRATE. Settings are now retrieved from the hardware.
    switch (this->state) {
        case wtmAppStateNoSerialConnection: {
            break;
        }
        case wtmAppStateStartWhenSerialInitalized: {
            if (serial.isInitialized()) {
                if (now > (this->serialOpenTime + 2)) { // let's give the serial connection some time (2 seconds)
                    ofLogNotice() << "init finished";
                    this->stopSensor(); // restart. just in case (the mainboard might already send data)
                    this->startSensor();
                }
            }
            break;
        }
        case wtmAppStateReceivingCalibrationResults: {
            while (serial.available()) {
                int c = serial.readByte();
                this->calibrationResultsString += (char)c;
                if ('\n' == c) {
                    ofxUILabelButton* button = (ofxUILabelButton*)gui->getWidget(kGUICalibrateName);
                    button->setLabelText(kGUICalibrateName);
                    
                    this->consumeCalibrationResults(this->calibrationResultsString.c_str());
                    this->calibrationResultsString.clear();
                    this->stopSensor();
                    this->startSensor();
                    break;
                }
            }
            break;
        }
        case wtmAppStateReceivingTouches: {
            if (serial.available() >= this->bytesPerFrame) {
                int len = serial.readBytes(this->recvBuffer, this->bytesPerFrame);
                
                if (len == this->bytesPerFrame) {
                    if (0 != this->lastRecvFrameTime) {
                        float now = ofGetElapsedTimef();
                        fpsCounter++;
                        if (now - this->lastRecvFrameTime > 1.0) {
                            this->updateFPSLabelWithValue(fpsCounter);
                            fpsCounter = 0;
                            this->lastRecvFrameTime = now;
                        }
                    } else
                        this->lastRecvFrameTime = ofGetElapsedTimef();
                    
                    this->consumePacketData();
                }
                if (this->bTrackBlobs) {
                    if (this->bNewDataToShow) {
                        this->blobTracker->update();
                        this->distributeTuio();
                        this->bNewDataToShow = false;
                    }
                }
            }
            break;
        }
        case wtmAppStateIdle:
        default:
            this->drainSerial();
            break;
    }
}

//--------------------------------------------------------------
void wtmApp::distributeTuio() {
    vector<ofxStoredBlobVO>& blobs = this->blobTracker->currentBlobs();
    
    float w = this->interpolator->getOutputWidth(), h = this->interpolator->getOutputHeight();
    int numBlobs = blobs.size();
	for(int i = 0; i < numBlobs; i++ )	{
		ofxStoredBlobVO& blob = blobs.at(i);
        
        this->tuioServer->registerCursorPosition(blob.id,
                                                 (float)blob.centroid.x / w,
                                                 (float)blob.centroid.y / h);
    }
    
    this->tuioServer->update();
}

//--------------------------------------------------------------
void wtmApp::draw() {
    if (this->texture && this->texture->isAllocated())
        this->texture->draw(0, 0, ofGetWidth(), ofGetHeight());

    if (this->bTrackBlobs) {
        if (wtmAppStateReceivingTouches == this->state && 0 < this->thresholdImageAlpha) {
            ofTexture* thresholdedTexture = this->blobTracker->currentTresholdedTexture();
            
            if (NULL != thresholdedTexture) {
                ofPushStyle();
                ofEnableAlphaBlending();
                ofSetColor(255, 0, 222, this->thresholdImageAlpha);
                
                thresholdedTexture->draw(0, 0, ofGetWidth(), ofGetHeight());
                
                ofDisableAlphaBlending();
                ofPopStyle();
            }
        }
        this->blobTracker->draw();
    }
}
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

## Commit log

2011-06-04 initial commit: 2 crosspoints prototype code
2011-06-07 single board mux
2011-06-22 Experimenting More debug output & third sensor row
2011-10-21 arduino code: faster measurements (writes to ports directory instead of using arduino core convenience functions).
2011-10-21 10-bit packed sending of sensor data.
2012-01-05 sampling done from interrupt triggered by reference signal.
2012-01-19 minor edits (prototype working again)
2012-01-20 pin/port changes
2012-01-20 attempt to implement measuring via PCM1308 adc.
2012-01-27 since spi is enabled now, pin 5 is used instead of pin 12 for peak detection
2012-04-13 spi for shift registers. reverting to atmega adc
2012-04-20 last cable grid prototype
2012-05-25 switch to new mux (74hc4051)
2012-06-01 mux switch bug search
2012-08-17 cleaned up sensor code and changed muxSPI code back to our old 16-channel mixes.
2012-12-14 pin changes for pcb layout
2013-05-17 cleaned arduino firmware + a TODO.
2013-05-24 in-firmware calibration
2013-06-21 calibration improved
2013-06-21 updated gitignore for open frameworks.
2013-06-28 dicking around with the FTDI serial driver settings on MacOS X – seems to be solved now and running fine at 500000bps. Needs driver hack, will write script for that soon.
    [wtmApp.cpp, wtmApp.h]
2013-07-12 added perl script to patch FTDI driver info.plist to support 500000 baud (aliased to 300baud) transfer for FTDI R series (required for fast framerate).
2013-07-12 patch ftdi info.plist: ask to disconnect all FTDI devices first and only reload kext if it is currently loaded.
2013-07-12 processing on OSX ftdi hack (see also: modify-ftdi-driver-settings.pl)
2013-07-12 began re-implementing our interpolation methods in open frameworks.
2013-08-02 ported our interpolators from previous processing code & added convenience method to switch to different interpolator settings.
2013-08-23 prevent gui title bar from leaving the app window. also: new slider for blob visualization.
    [wtmApp.cpp, wtmApp.h]
2013-08-23 additional settings for adaptive thresholding + a setting to apply a greyscale gamma to the data read from the sensor.
2013-08-23 added TUIO output (currently hardcoded to localhost, port 3333).
2013-08-30 blob minimum area now dependent on current sensor image dimensions.
2013-09-06 firmware: added command to stop the transmission of sensor data.
2013-09-06 calibrate button, start/stop button, timing recovery after window resize
    there is now a separate "calibrate" button to call the calibration program. the start button will turn into a stop button while the tracker is running. also, the sensor will automatically recover the correct data timing when the window has been resized.
    [wtmApp.cpp, wtmApp.h]
2013-09-06 added an fps label (e.g. tracking the amount of sensor packets received per second).
2013-09-06 show "calibrating…" as button label while the calibration process is running & show proper interpolation type as label when the app is launched.
2013-12-06 adaptations from new sensor layout
2013-12-06 improved firmware default values & updated calibration algorithm.
2013-12-28 modifications for Xcode5 and openFrameworks 0.8.0 on OSX 10.9
    - I undid our changes in ofTypes.h and used the oF 0.8.0 project builder to
    set up a new, clean project. No "tr1/memory file not found" error.
    Works with the 10.9 Base SDK.
    - Several oF libs are 32-bit-only builds. I set the project build setting
    "Architectures" to "32-bit Intel".
    - I let Xcode find all header files by setting "User Header Search Paths" to
    "$(SRCROOT)/src/3rd-party" (recursive) for Target/wiretouch_monitor.
2014-01-31 send gui-visible settings to board when the serial connection is established.
2014-11-05 ofxUIDropDownList has issues (see: https://github.com/rezaali/ofxUI/issues/68 ) The current implementation uses a self-made "modern" disclosure menu as a workaround.
    [wtmApp.cpp, wtmApp.h]
2014-11-06 cleaned up GUI behavior. problem with serial connection.
    [wtmApp.cpp, wtmApp.h]
2014-11-11 minor GUI changes and typo corrections
    [main.cpp, wtmApp.cpp, wtmApp.h]
2014-11-13 minor GUI fixes removed unnecessary ofxui assets
    [main.cpp, wtmApp.cpp, wtmApp.h]
2014-11-14 ofxui+ofxXmlSettings don't store the values of ofxUIDropDownList correctly. storing settings now by using cjson. might need some refactoring later on.
    [wtmApp.cpp, wtmApp.h]
2014-11-18 minor changes: * don't send all parameters after calibration * activate blob tracking boolean after loadsettings()
2014-11-18 don't send all parameters after calibration
2014-11-19 * new feature: reset calibration * minor GUI adjustments
    [wtmApp.cpp, wtmApp.h]
2014-11-23 minor GUI adjustments: * upsampling slider doesn't create jitter * blob detection state loads correctly testing portrait-mode sensor matrix
    [wtmApp.cpp, wtmApp.h]
2015-02-18 added the board schematics and CAD files
    [motherboard-board.brd, motherboard-board.sch, sensor-board.brd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]
2016-04-01 added the sensor plate gerber files we designed for the audio-tactile map
    [AUX1.GBR, AUX2.GBR, LAYER1.GBR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]
2016-04-16 * minor modification of the firmware.ino file to make the updated * Arduino IDE preprocesser work (fixes the "was not declared in this scope" * errors) * updated the README file * switching to Xcode 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
    [firmware.ino, wtmApp.cpp, wtmApp.h]
2016-05-01 Cleaning up the motherboard schematic in order to get a better overview. No functional changes.
    [motherboard-board_cleanup.brd, motherboard-board_cleanup.sch]
2016-05-05 The motherboard's schematic was missing a connection (OUT_B to R19 and the switch's S3). We fixed this using a short wire, but forgot to update the eagle files. Many thanks to Mike Farr for pointing 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
    [motherboard-board_cleanup.sch]
2016-05-06 The motherboard version 1.21 includes the missing connection on the OPA2350-5. I also worked a bit on the routing and added a printout of the schematics.
    [motherboard_v1_20.brd, motherboard_v1_20.sch, motherboard_v1_21.brd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]
2016-05-07 cosmetic changes on the signal-board schematic putting the 1.21 version in a seperate directory
    [motherboard-board.brd, motherboard-board.sch, motherboard_v1_21.brd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]
2016-05-08 adding a cleaned up version of the sensor-board
    [motherboard_v1_21.sch, sensor-board_v1_21.sch, signal-board_v1_21.sch]
2016-05-29 Corrected an error in the signal board schematic. GND was connected to OPA1's +IN_B.
    [signal-board_v1_21.sch]
2016-06-26 wiretouch hardware v1.23 added a few decoupling capacitors new board layout
    [main-board_v1_23.brd, main-board_v1_23.sch, sensor-board_v1_23.brd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]
2016-09-01 clean up
    [main-board_v1_23.brd, main-board_v1_23.sch, motherboard-board.brd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]
2016-09-03 hardware build v1.3: * I exchanged the 74HC4067 multiplexers with MAX306CPI+ multiplexers. * I simplified the signal board's connection to the sensor panel: no more criss-crossing. Pin 1-16 belong to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
    [main-board_v1_3.brd, main-board_v1_3.sch, sensor-board_v1_3.brd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]
2016-09-04 added a compiled version (OSX 10.11) of wiretouch_monitor
2017-06-11 The patched FTDI driver isn't working in OSX 10.12.5
    While I am trying to figure out what is going on, please use the
    default driver (com.apple.driver.AppleUSBFTDI).
    I have reduced the symbol rate accordingly to Apple's maximum, which is 115200 BAUD.
    This reduces the framerate to ca. 11 fps. :(
2017-06-11 FTDI driver is causing troubles

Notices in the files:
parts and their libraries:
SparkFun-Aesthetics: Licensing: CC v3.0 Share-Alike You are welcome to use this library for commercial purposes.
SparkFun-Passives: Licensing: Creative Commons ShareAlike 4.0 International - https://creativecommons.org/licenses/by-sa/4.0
